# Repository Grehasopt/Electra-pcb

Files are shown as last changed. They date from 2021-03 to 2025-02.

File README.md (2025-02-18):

# Electra
Remote Relays Board

## Electra
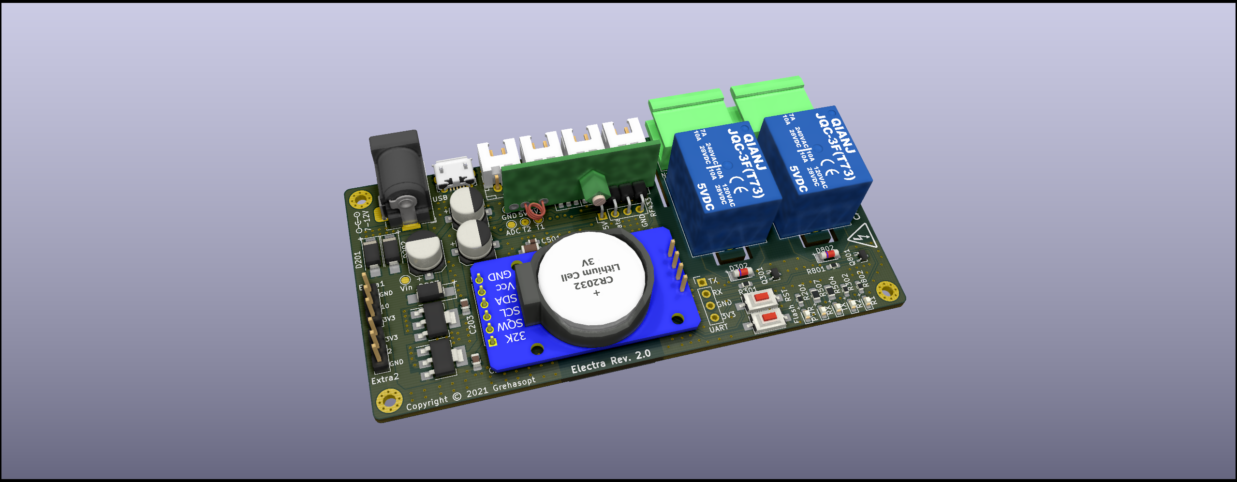
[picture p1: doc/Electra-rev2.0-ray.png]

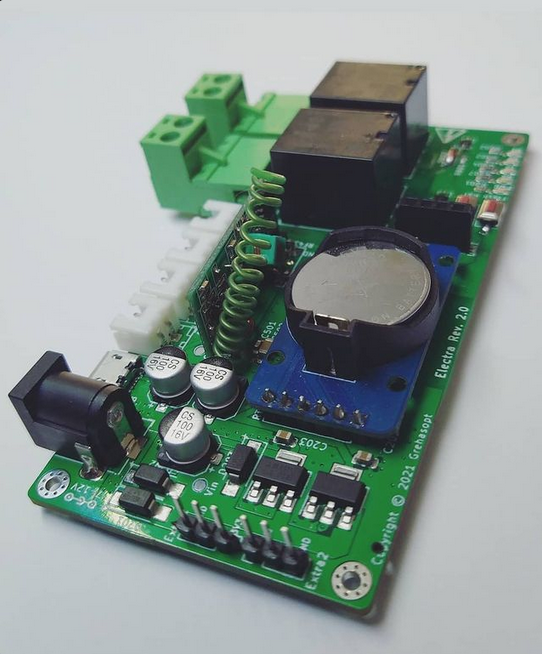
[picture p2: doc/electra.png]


> [!CAUTION]
>
> This project involves the use of 230V AC mains power and contains high-voltage components.
> Working with mains electricity can be extremely dangerous and may result in serious injury,
> death, or property damage if not handled correctly.
>
> This design is provided "as-is" and for educational purposes only.
> Only individuals with the appropriate electrical expertise and experience should attempt to
> reproduce or work with this project. You are solely responsible for ensuring that your work
> with this hardware complies with all applicable safety standards, laws, and regulations.

---

### Schematic

#### Page 1
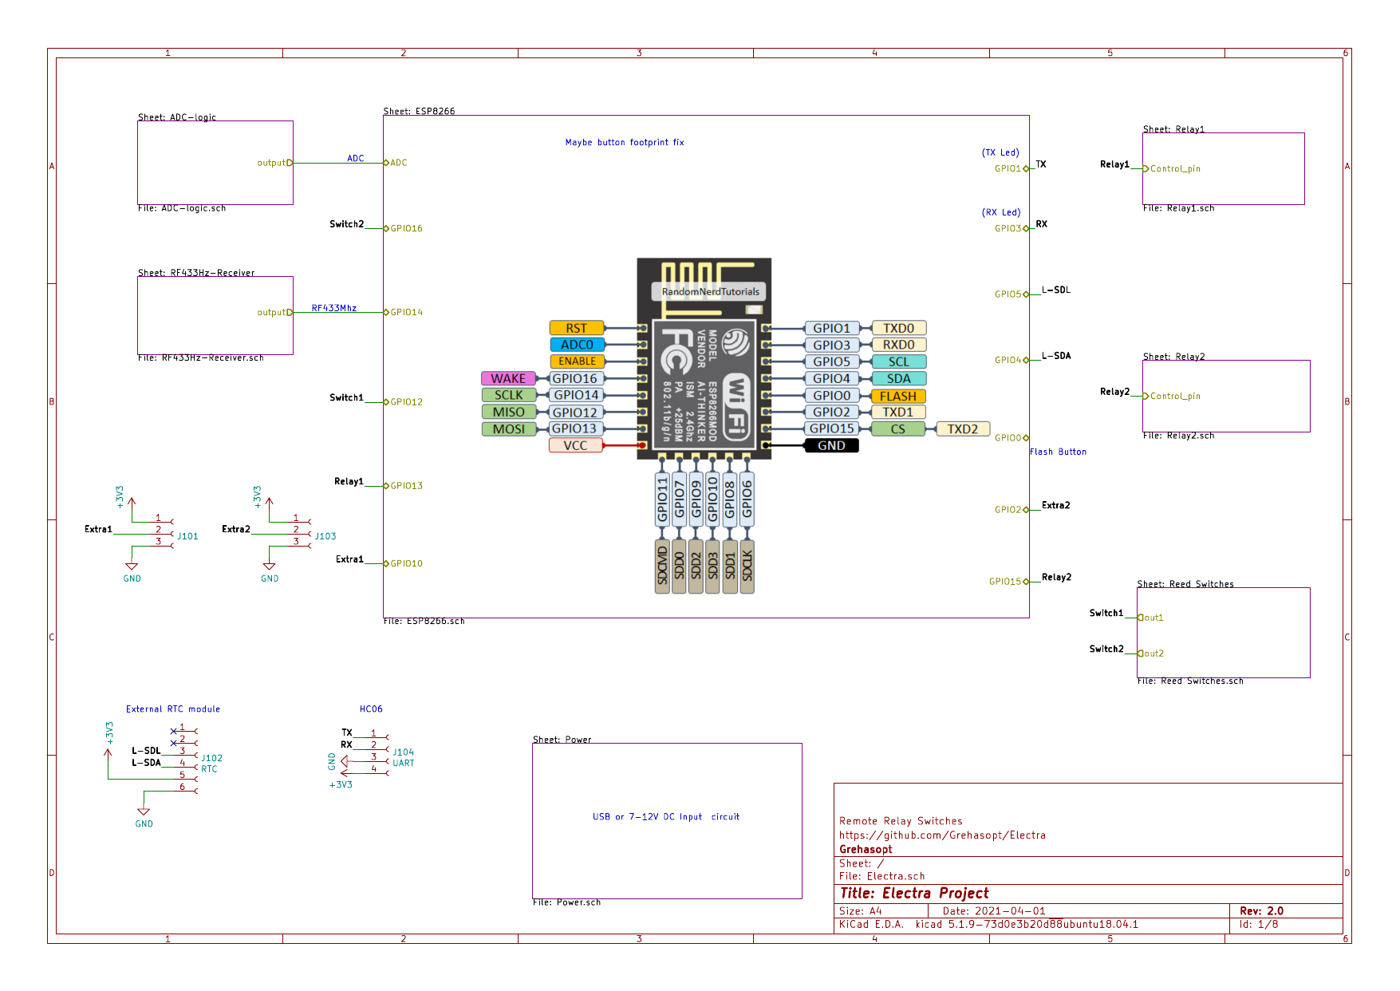
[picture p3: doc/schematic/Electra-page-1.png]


#### Page 2
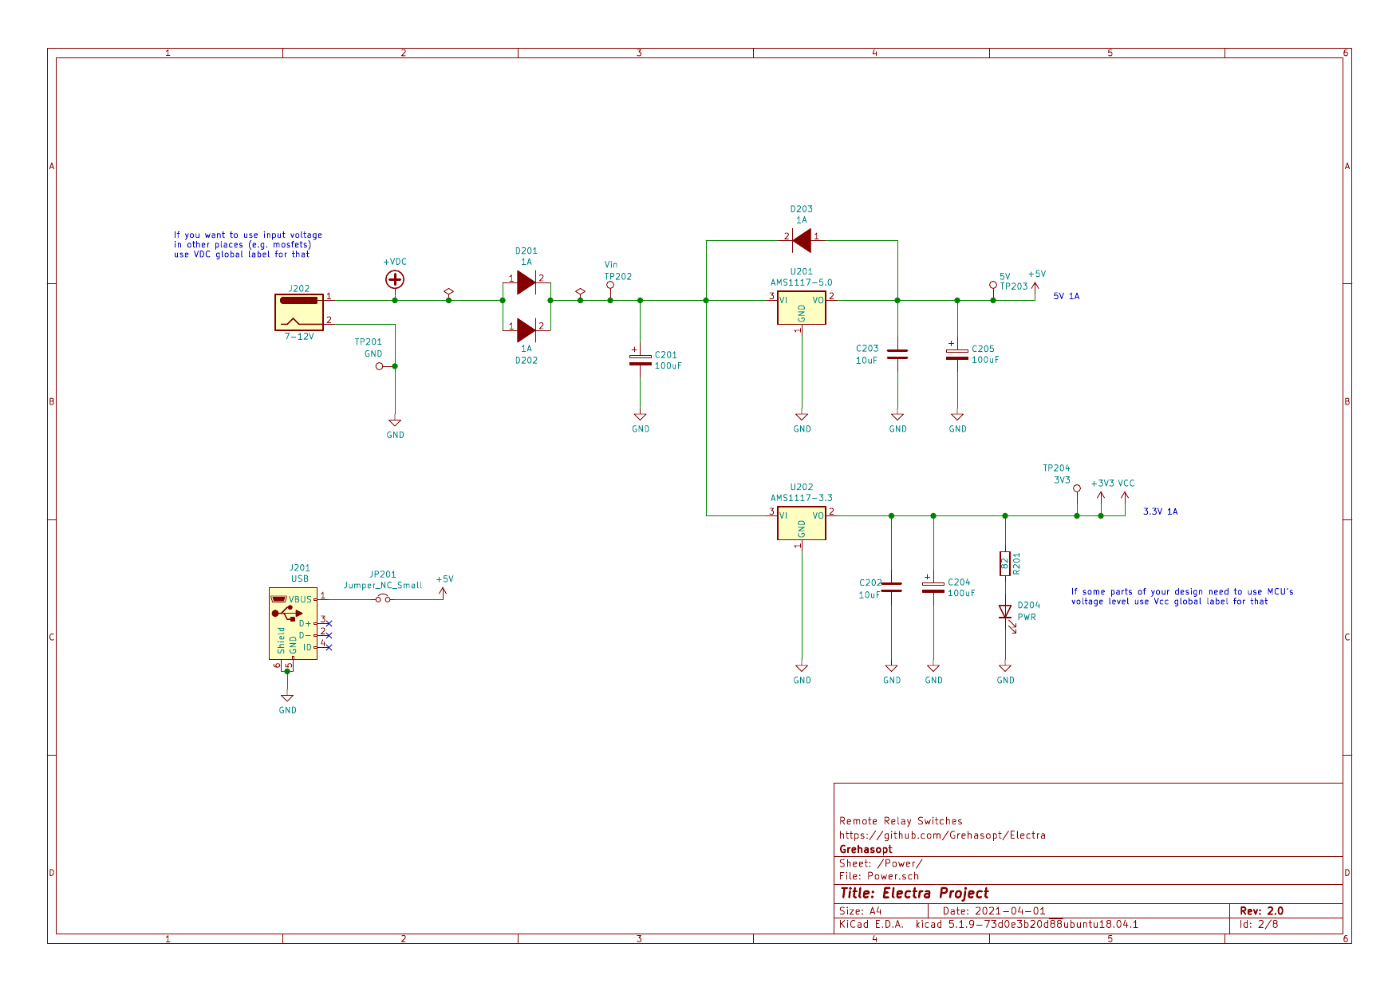
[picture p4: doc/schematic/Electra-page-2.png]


#### Page 3
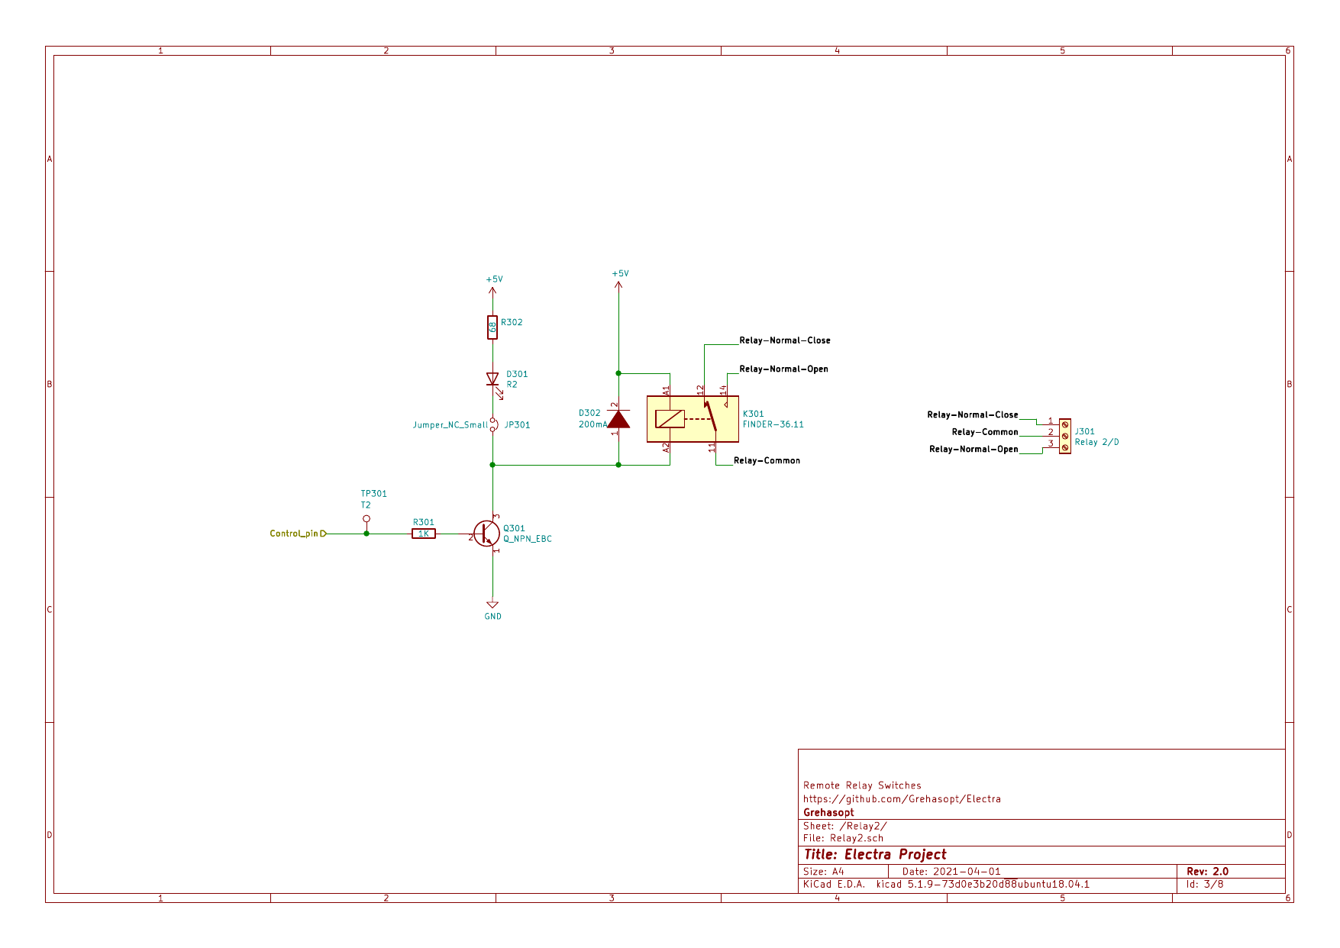
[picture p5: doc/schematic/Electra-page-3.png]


#### Page 4
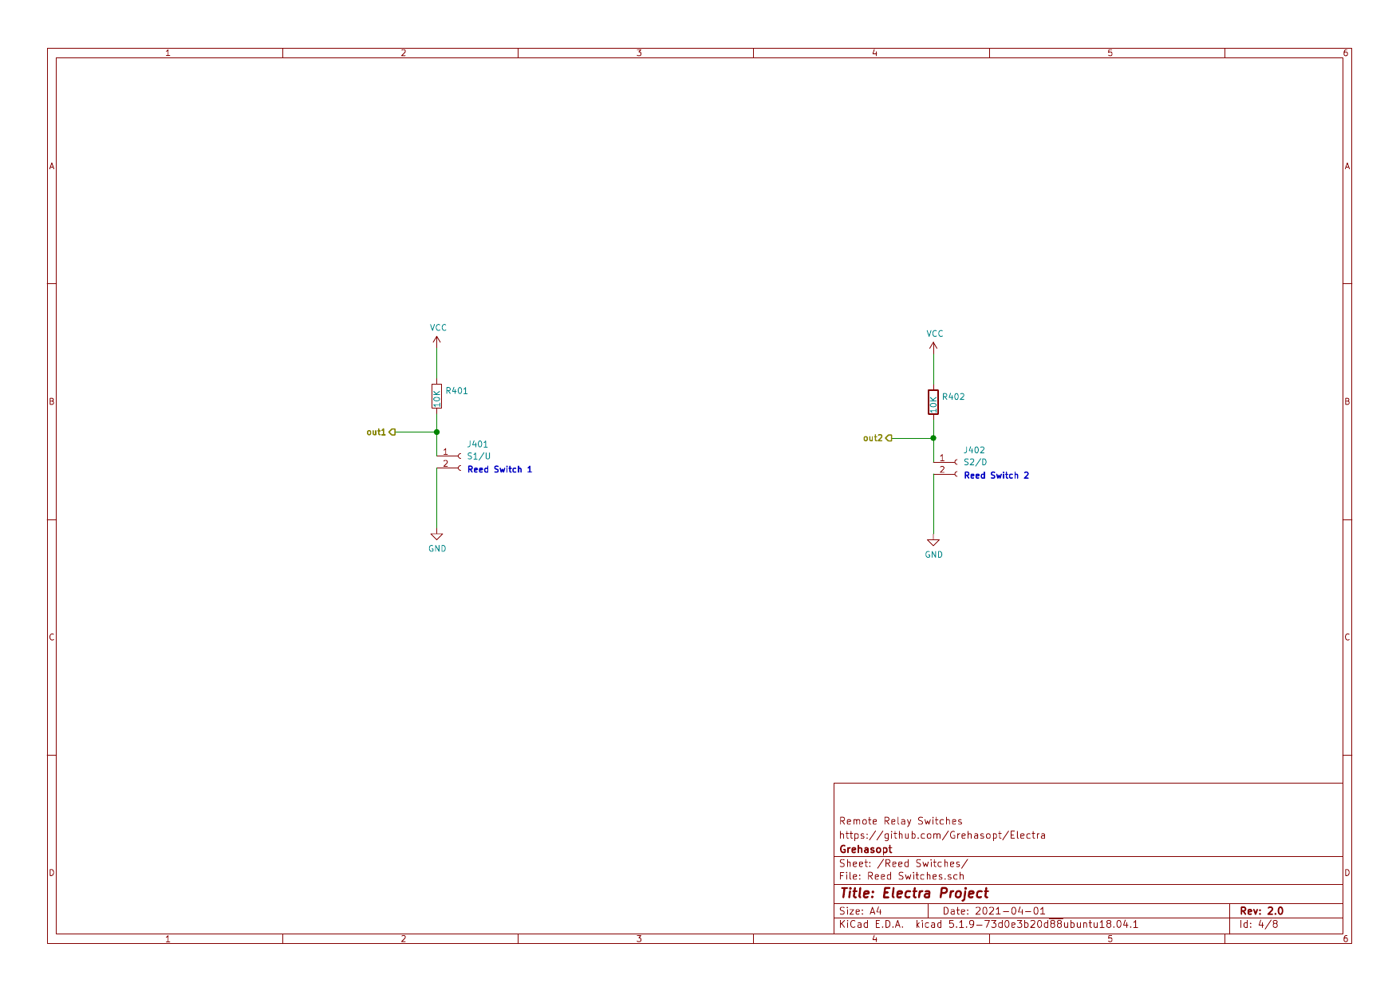
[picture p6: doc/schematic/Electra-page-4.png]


#### Page 5
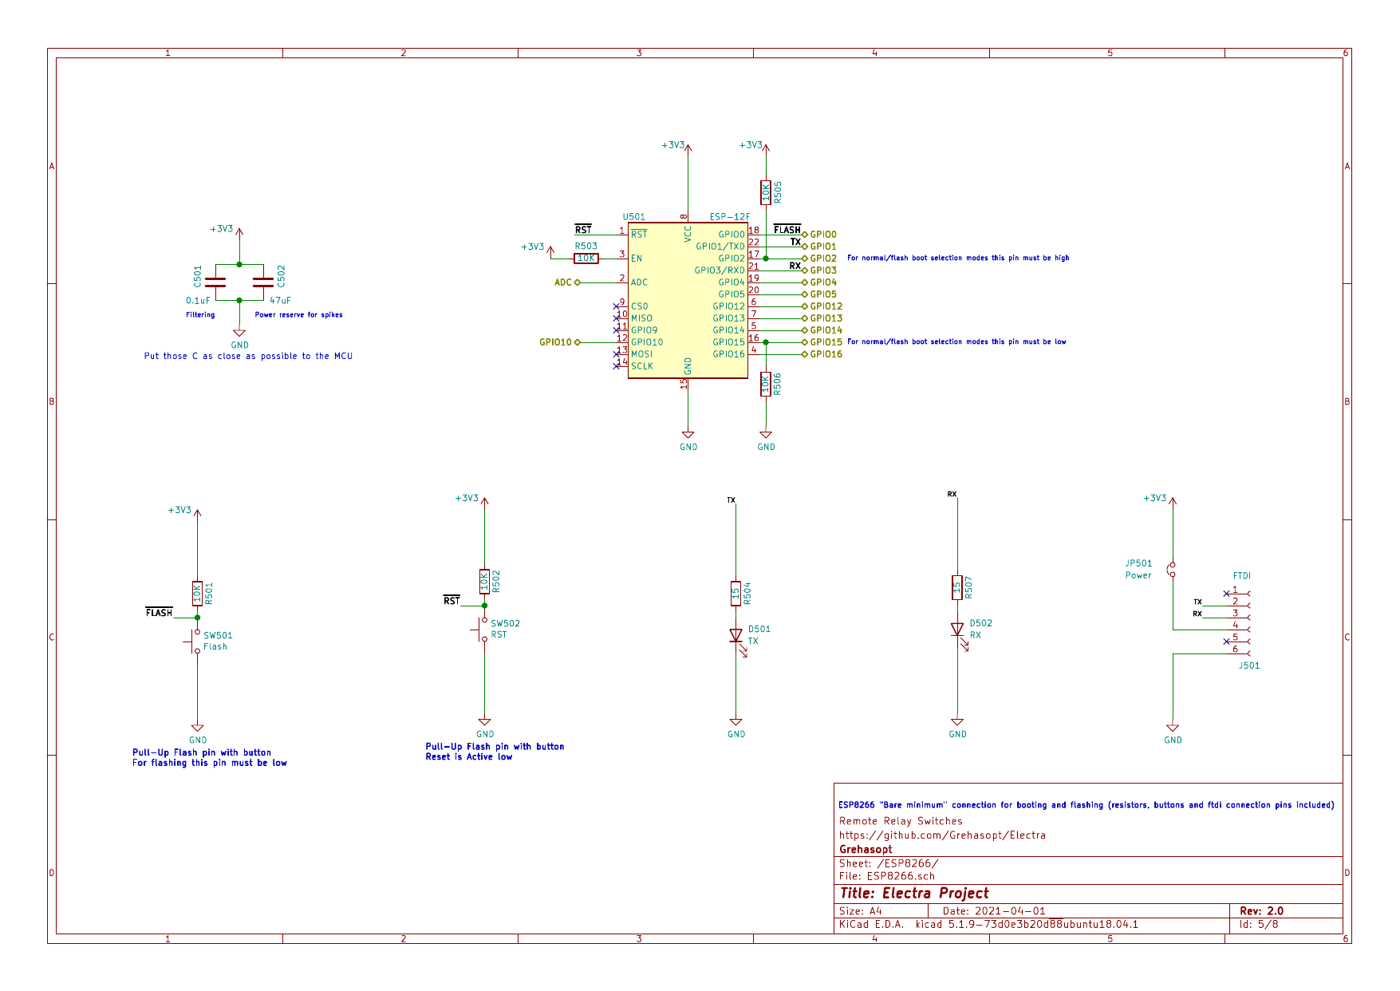
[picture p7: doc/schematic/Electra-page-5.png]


#### Page 6
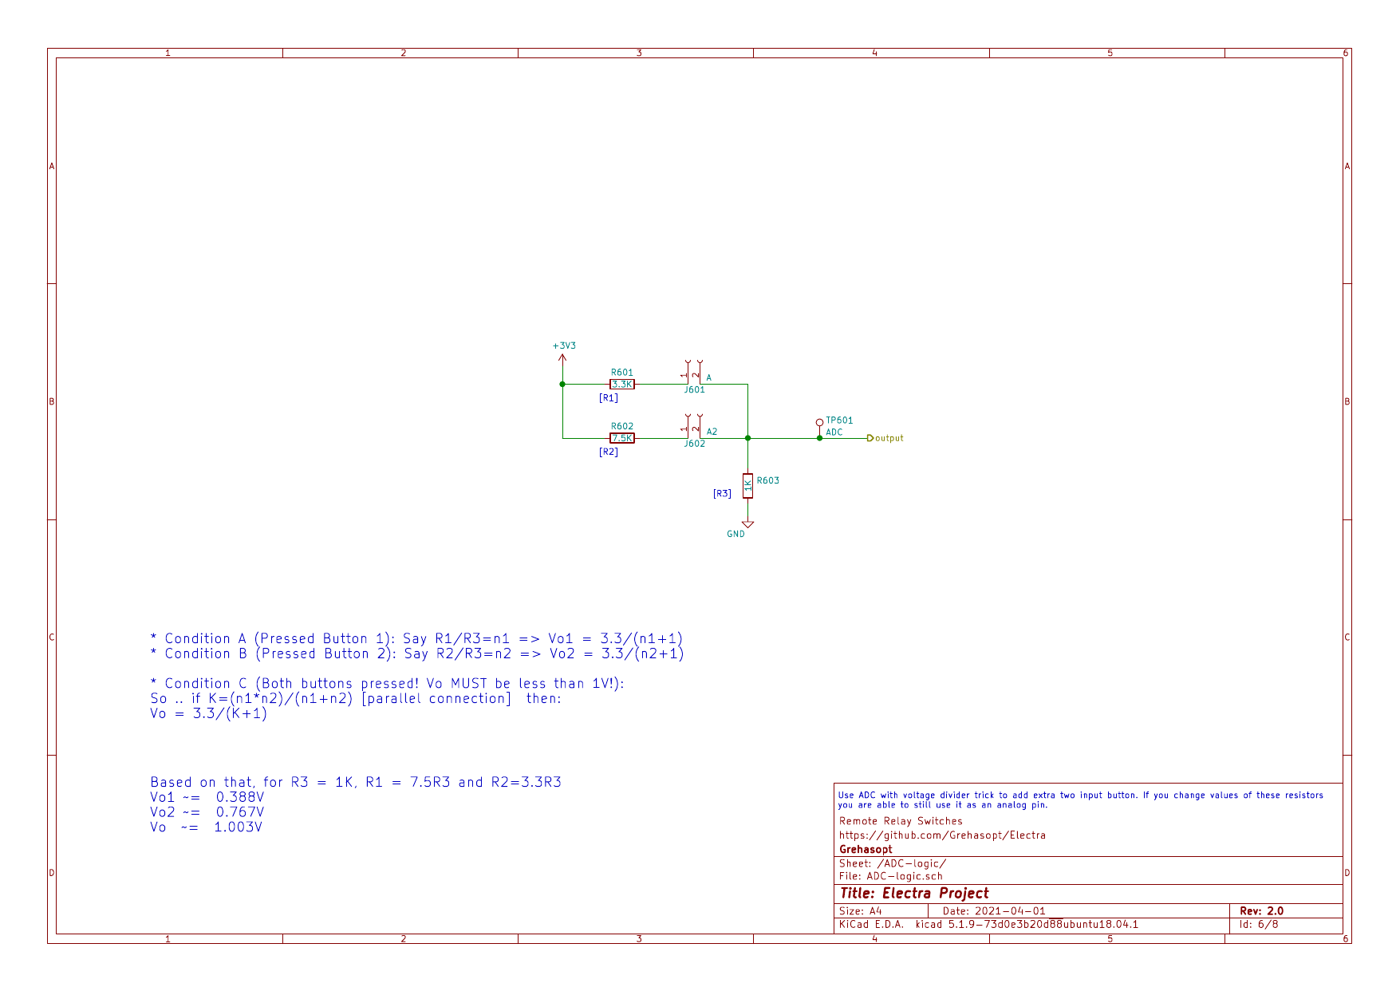
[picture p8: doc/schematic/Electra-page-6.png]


#### Page 7
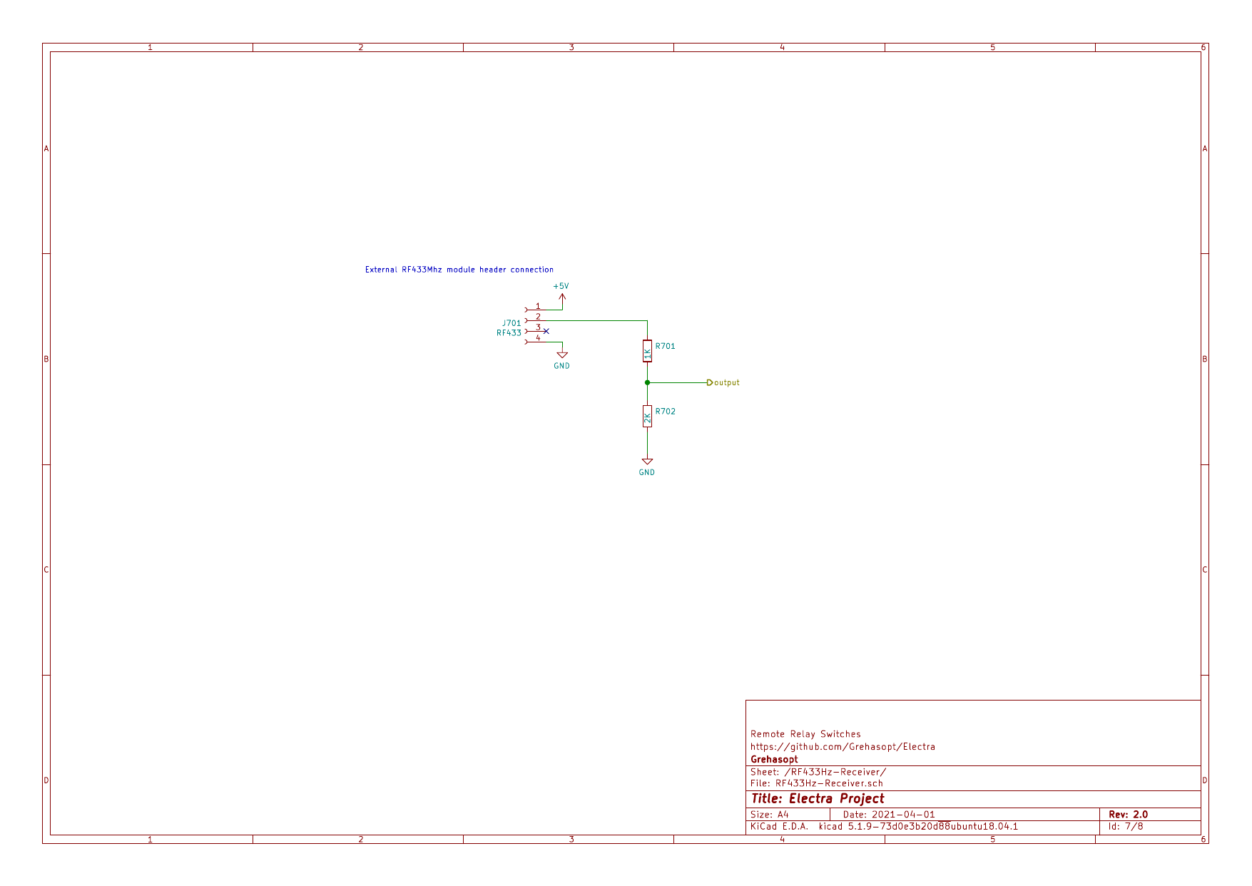
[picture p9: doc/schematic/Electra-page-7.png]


#### Page 8
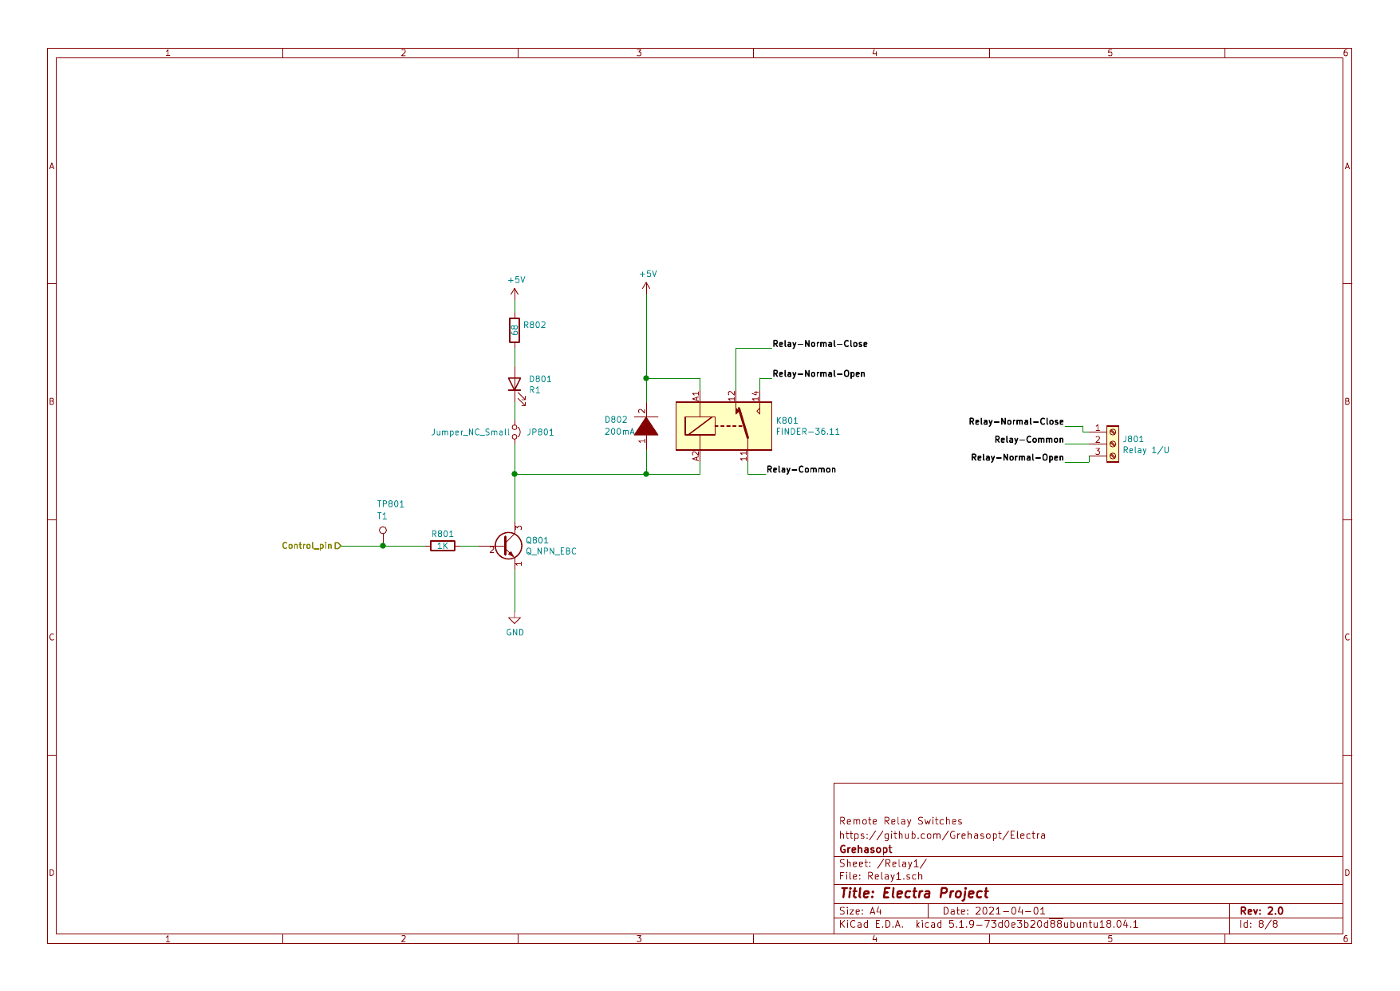
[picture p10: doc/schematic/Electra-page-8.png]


## License
This project is licensed under the CERN-OHL-S-2.0 (applies from the very first commit on Mar 7, 2021) with the added condition that it may not be used for commercial purposes without prior permission from the license holder.

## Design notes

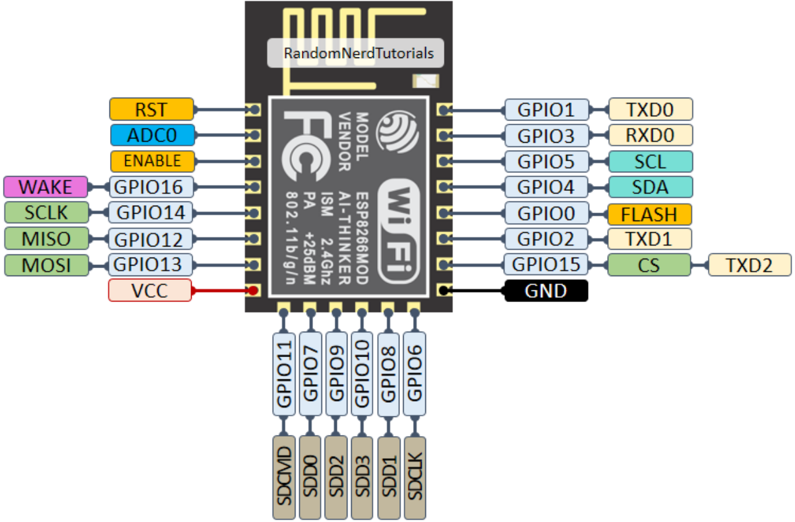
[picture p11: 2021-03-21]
doc/ESP8266-pinout.png

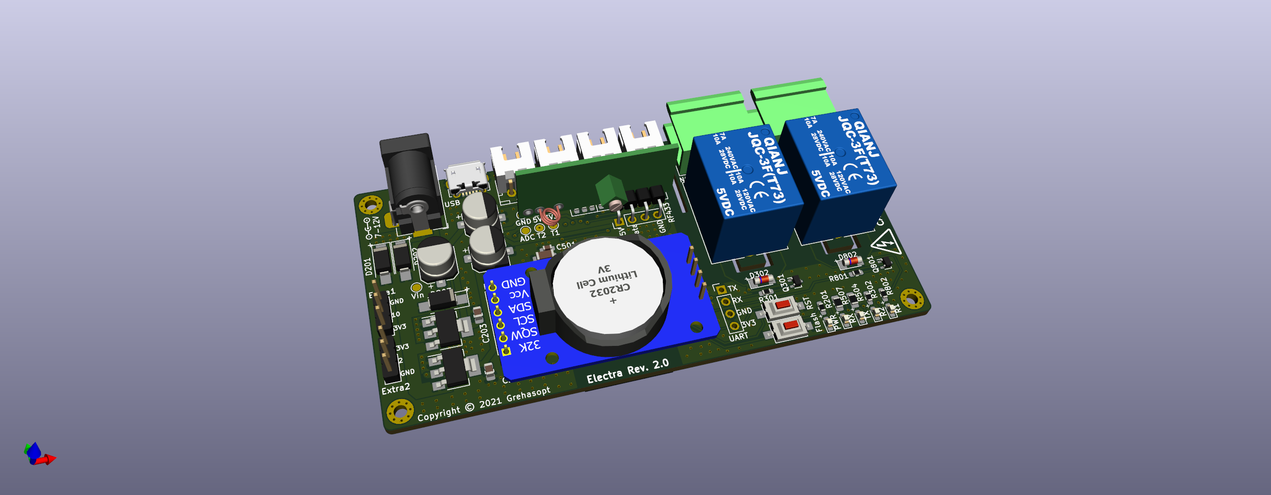
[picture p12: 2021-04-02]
doc/Electra-rev2.0.png

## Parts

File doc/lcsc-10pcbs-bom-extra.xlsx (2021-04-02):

LCSC Part Number | Manufacture Part Number | Manufacturer | Package | Customer # | Description | RoHS | Order Qty. | Min\Mult Order Qty. | Unit Price | Order Price | Product Link
C399562 | HF3FF/005-1ZS | HF(Xiamen Hongfa Electroacoustic) | Through Hole |  | General Purpose Non Latching 5VDC SPDT Through Hole Relays RoHS | yes | 20 | 1 | 0.3517 | 3.87 | lcsc.com/product-detail/Relays_HF-Xiamen-Hongfa-Electroacoustic-HF3FF-005-1ZS_C399562.html
C82891 | ESP-12F(ESP8266MOD) | Ai-Thinker | WIFI Module |  | WIFI Module WIFI Modules RoHS | yes | 10 | 1 | 1.52 | 12.16 | lcsc.com/product-detail/WIFI-Modules_Ai-Thinker-ESP-12F-ESP8266MOD_C82891.html
C71370 | WJ2EDGK-5.08-2P | Ningbo Kangnex Elec | P=5.08mm |  | Plug,Female Socket 2 1 0.200"（5.08mm） 2 P=5.08mm Pluggable System Terminal Block RoHS | yes | 20 | 1 | 0.1028 | 2.06 | lcsc.com/product-detail/Pluggable-System-Terminal-Block_Ningbo-Kangnex-Elec-WJ2EDGK-5-08-2P_C71370.html
C10418 | 920-E52A2021S10100 | Jing Extension of the Electronic Co. | SMD |  | USB - Micro B Female USB 2.0 5 SMD USB Connectors RoHS | yes | 10 | 5 | 0.0663 | 0.66 | lcsc.com/product-detail/USB-Connectors_Jing-Extension-of-the-Electronic-Co-920-E52A2021S10100_C10418.html
C319365 | 1TS002E-2400-2500-CT | HYP (Hongyuan Precision) | SMD,6.1x3.7x2.5mm |  | SPST 50mA @ 12VDC Vertical Rectangle button SMD,6.1x3.7x2.5mm Tactile Switches RoHS | yes | 20 | 20 | 0.0381 | 1.52 | lcsc.com/product-detail/Tactile-Switches_HYP-Hongyuan-Precision-1TS002E-2400-2500-CT_C319365.html
C16214 | DC-005 5.5-2.0MM | BOOMELE(Boom Precision Elec) | Through Hole |  | Through Hole AC/DC Power Plugs & Receptacles RoHS | yes | 20 | 10 | 0.043 | 0.86 | lcsc.com/product-detail/AC-DC-Power-Plugs-Receptacles_BOOMELE-Boom-Precision-Elec-DC-005-5-5-2-0MM_C16214.html
C8425 | WJ2EDGR-5.08-3P | Ningbo Kangnex Elec | P=5.08mm |  | 插针/板端，Covered（2Sided） 3 1 0.200"（5.08mm） 3 P=5.08mm Pluggable System Terminal Block RoHS | yes | 20 | 10 | 0.0508 | 1.02 | lcsc.com/product-detail/Pluggable-System-Terminal-Block_Ningbo-Kangnex-Elec-WJ2EDGR-5-08-3P_C8425.html

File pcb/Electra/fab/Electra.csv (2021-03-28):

Comment | Designator | Footprint | LCSC | Quantity
10uF | C201 | Capacitor_SMD:C_1210_3225Metric_Pad1.33x2.70mm_HandSolder | C92800 | 1
100uF | C203,C208 | Capacitor_SMD:CP_Elec_5x5.4 | C96182 | 2
0.1uF | C202,C204,C601 | Capacitor_SMD:C_0603_1608Metric_Pad1.08x0.95mm_HandSolder | C478888 | 3
22uF | C205,C206 | Capacitor_SMD:C_1210_3225Metric_Pad1.33x2.70mm_HandSolder | C319200 | 2
75pF | C207 | Capacitor_SMD:C_0603_1608Metric_Pad1.08x0.95mm_HandSolder | C1681 | 1
47uF | C602 | Capacitor_SMD:C_0603_1608Metric_Pad1.08x0.95mm_HandSolder | C140782 | 1
DIODE 3A | D201 | Diode_SMD:D_SMA | C18905 | 1
200mA diodes | D302,D402 | Diode_SMD:D_SOD-323 | C89953 | 2
Red led | D301,D401 | LED_SMD:LED_0603_1608Metric_Pad1.05x0.95mm_HandSolder | C84263 | 2
Green led | D202 | LED_SMD:LED_0603_1608Metric_Pad1.05x0.95mm_HandSolder | C205443 | 1
Yellow led | D601,D602 | LED_SMD:LED_0603_1608Metric_Pad1.05x0.95mm_HandSolder | C84268 | 2
8-28V | J201 | Connector_BarrelJack:BarrelJack_Horizontal | C319099 | 1
USB micro b | J202 | Connector_USB:USB_Micro-B_Molex-105017-0001 | C10418 | 1
AC Terminals | J301,J401 | TerminalBlock:TerminalBlock_bornier-3_P5.08mm | C8377 | 2
Relay | K301,K401 | Relay_THT:Relay_SPDT_Finder_36.11 | C9221 | 2
15uH | L201 | Inductor_SMD:L_10.4x10.4_H4.8 | C182182 | 1
200mA NPN BJT | Q301,Q401 | Package_TO_SOT_SMD:SOT-323_SC-70 | C75568 | 2
BSS138 | Q801 | Package_TO_SOT_SMD:SOT-23 | C426569 | 1
511K | R201 | Resistor_SMD:R_0603_1608Metric_Pad0.98x0.95mm_HandSolder | C23194 | 1
105K | R202 | Resistor_SMD:R_0603_1608Metric_Pad0.98x0.95mm_HandSolder | C16840 | 1
80 | R203,R604,R607 | Resistor_SMD:R_0603_1608Metric_Pad0.98x0.95mm_HandSolder | C202954 | 3
49.9 | R204 | Resistor_SMD:R_0603_1608Metric_Pad0.98x0.95mm_HandSolder | C163926 | 1
100K | R205 | Resistor_SMD:R_0603_1608Metric_Pad0.98x0.95mm_HandSolder | C15458 | 1
13.3K | R206 | Resistor_SMD:R_0603_1608Metric_Pad0.98x0.95mm_HandSolder | C25952 | 1
1K | R301,R401,R703 | Resistor_SMD:R_0603_1608Metric_Pad0.98x0.95mm_HandSolder | C115325 | 3
150 | R302,R402 | Resistor_SMD:R_0603_1608Metric_Pad0.98x0.95mm_HandSolder | C103302 | 2
10K | R501,R502,R601,R602,R603,R605,R606,R801,R802 | Resistor_SMD:R_0603_1608Metric_Pad0.98x0.95mm_HandSolder | C98220 | 9
3.57K | R701 | Resistor_SMD:R_0603_1608Metric_Pad0.98x0.95mm_HandSolder | C22998 | 1
7.5K | R702 | Resistor_SMD:R_0603_1608Metric_Pad0.98x0.95mm_HandSolder | C310285 | 1
Buttons | SW601,SW602 | Button_Switch_SMD:SW_SPST_EVQPE1 | C557591 | 2
AMS1117-3.3 | U201 | Package_TO_SOT_SMD:SOT-223-3_TabPin2 | C347222 | 1
TPS54202DDCR | U202 | Package_TO_SOT_SMD:SOT-23-6 | C191884 | 1
ESP-12F | U601 | RF_Module:ESP-12E | C82891 | 1
blue led | DXXX | LED_SMD:LED_0603_1608Metric_Pad1.05x0.95mm_HandSolder | C193191 | 2
blue resistor | RXXX | Resistor_SMD:R_0603_1608Metric_Pad0.98x0.95mm_HandSolder | C319824 | 2
terminal male block | EXX1, EXX2 | - | C71370 | 2

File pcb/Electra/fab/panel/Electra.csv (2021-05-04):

Comment | Designator | Footprint | LCSC
100uF | C201,C204,C205 | Capacitor_SMD:CP_Elec_6.3x5.4 | C97805
10uF | C202,C203 | Capacitor_SMD:C_0805_2012Metric_Pad1.18x1.45mm_HandSolder | C15850
0.1uF | C501 | Capacitor_SMD:C_0603_1608Metric_Pad1.08x0.95mm_HandSolder | C14663
47uF | C502 | Capacitor_SMD:C_1206_3216Metric_Pad1.33x1.80mm_HandSolder | C96123
1A | D201,D202,D203 | Diode_SMD:D_SMA_Handsoldering | C95872
PWR | D204 | LED_SMD:LED_0603_1608Metric_Pad1.05x0.95mm_HandSolder | C72043
R2 | D301 | LED_SMD:LED_0603_1608Metric_Pad1.05x0.95mm_HandSolder | C2286
200mA | D302,D802 | Diode_SMD:D_MiniMELF | C9808
TX | D501 | LED_SMD:LED_0603_1608Metric_Pad1.05x0.95mm_HandSolder | C72041
RX | D502 | LED_SMD:LED_0603_1608Metric_Pad1.05x0.95mm_HandSolder | C72041
R1 | D801 | LED_SMD:LED_0603_1608Metric_Pad1.05x0.95mm_HandSolder | C2286
USB | J201 | Connector_USB:USB_Micro-B_Molex-105017-0001 | C10418
7-12V | J202 | Connector_BarrelJack:BarrelJack_Horizontal | C16214
Relay 2/D | J301 | TerminalBlock:TerminalBlock_bornier-3_P5.08mm | C8425
Relay 1/U | J801 | TerminalBlock:TerminalBlock_bornier-3_P5.08mm | C8425
FINDER-36.11 | K301,K801 | Relay_THT:Relay_SPDT_Finder_36.11 | C399562
Q_NPN_EBC | Q301,Q801 | Package_TO_SOT_SMD:SOT-323_SC-70 | C75568
82 | R201 | Resistor_SMD:R_0603_1608Metric_Pad0.98x0.95mm_HandSolder | C23255
1K | R301,R603,R701,R801 | Resistor_SMD:R_0603_1608Metric_Pad0.98x0.95mm_HandSolder | C21190
68 | R302,R802 | Resistor_SMD:R_0603_1608Metric_Pad0.98x0.95mm_HandSolder | C27592
10K | R401,R402,R501,R502,R503,R505,R506 | Resistor_SMD:R_0603_1608Metric_Pad0.98x0.95mm_HandSolder | C25804
15 | R504,R507 | Resistor_SMD:R_0805_2012Metric_Pad1.20x1.40mm_HandSolder | C17480
3.3K | R601 | Resistor_SMD:R_0603_1608Metric_Pad0.98x0.95mm_HandSolder | C22978
7.5K | R602 | Resistor_SMD:R_0603_1608Metric_Pad0.98x0.95mm_HandSolder | C23234
2K | R702 | Resistor_SMD:R_0603_1608Metric_Pad0.98x0.95mm_HandSolder | C22975
Flash | SW501 | Button_Switch_SMD:SW_SPST_CK_RS282G05A3 | C329185
RST | SW502 | Button_Switch_SMD:SW_SPST_CK_RS282G05A3 | C329185
AMS1117-5.0 | U201 | Package_TO_SOT_SMD:SOT-223-3_TabPin2 | C6187
AMS1117-3.3 | U202 | Package_TO_SOT_SMD:SOT-223-3_TabPin2 | C6186
ESP-12F | U501 | RF_Module:ESP-12E | C82891

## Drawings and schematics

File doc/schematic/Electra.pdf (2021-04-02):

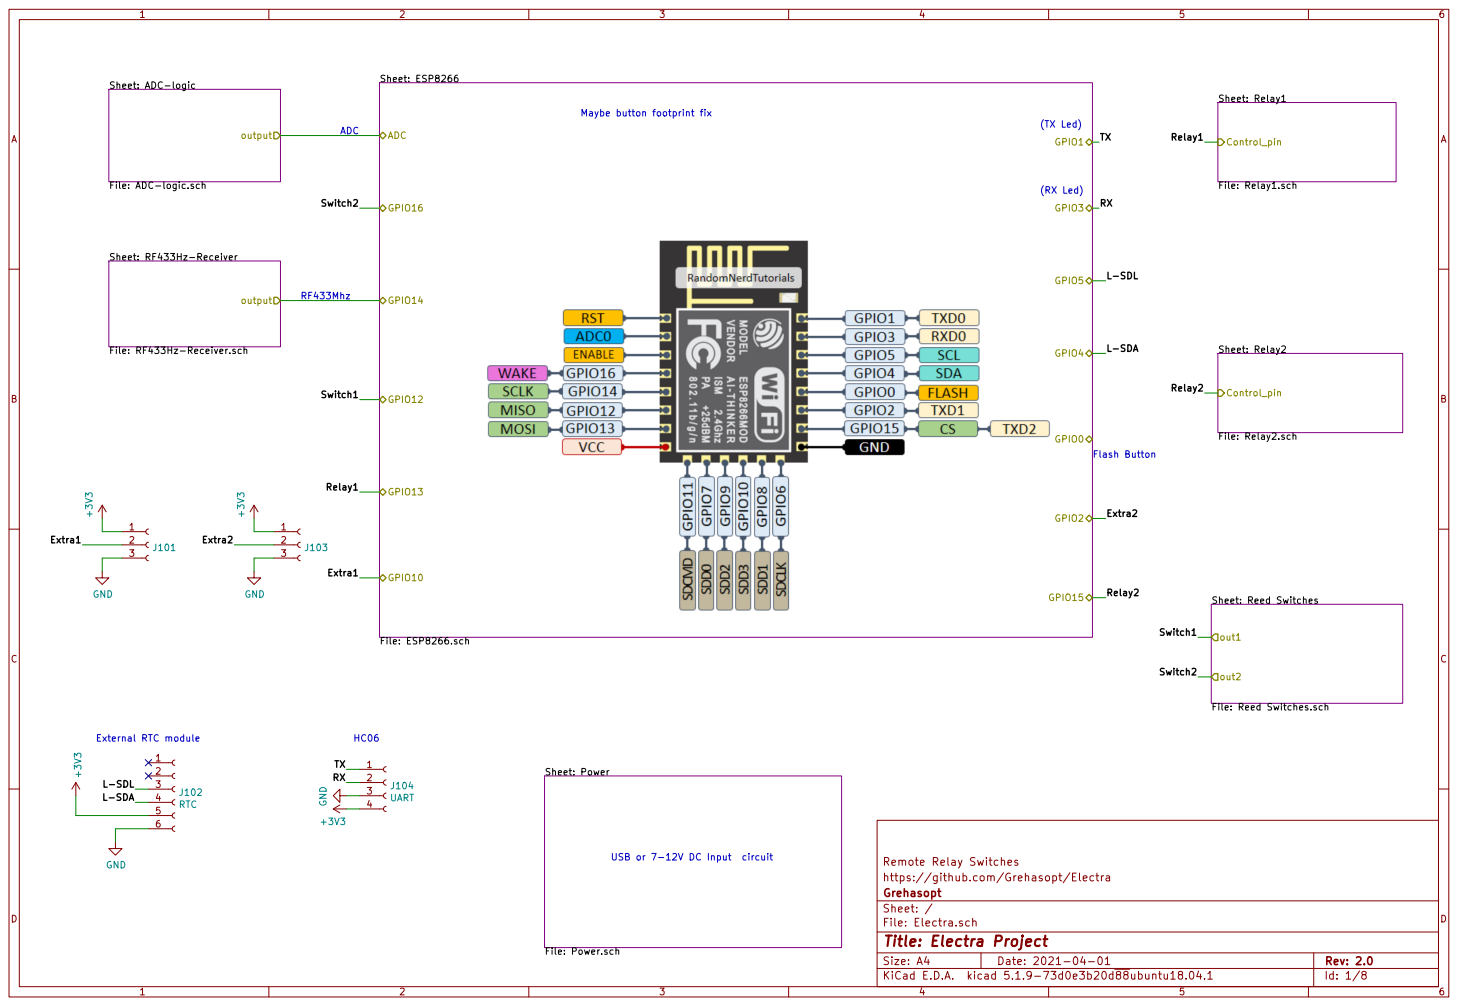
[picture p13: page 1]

output Sheet: ADC-logic

Control_pin Sheet: RF433Hz-Receiver File: RF433Hz-Receiver.sch

File: ADC-logic.sch

L-SDA
Control_pin Sheet: Reed Switches File: Reed Switches.sch

Remote Relay Switches
https://github.com/Grehasopt/Electra
Id: 1/8 Title: Electra Project File: Electra.sch Sheet: / Grehasopt

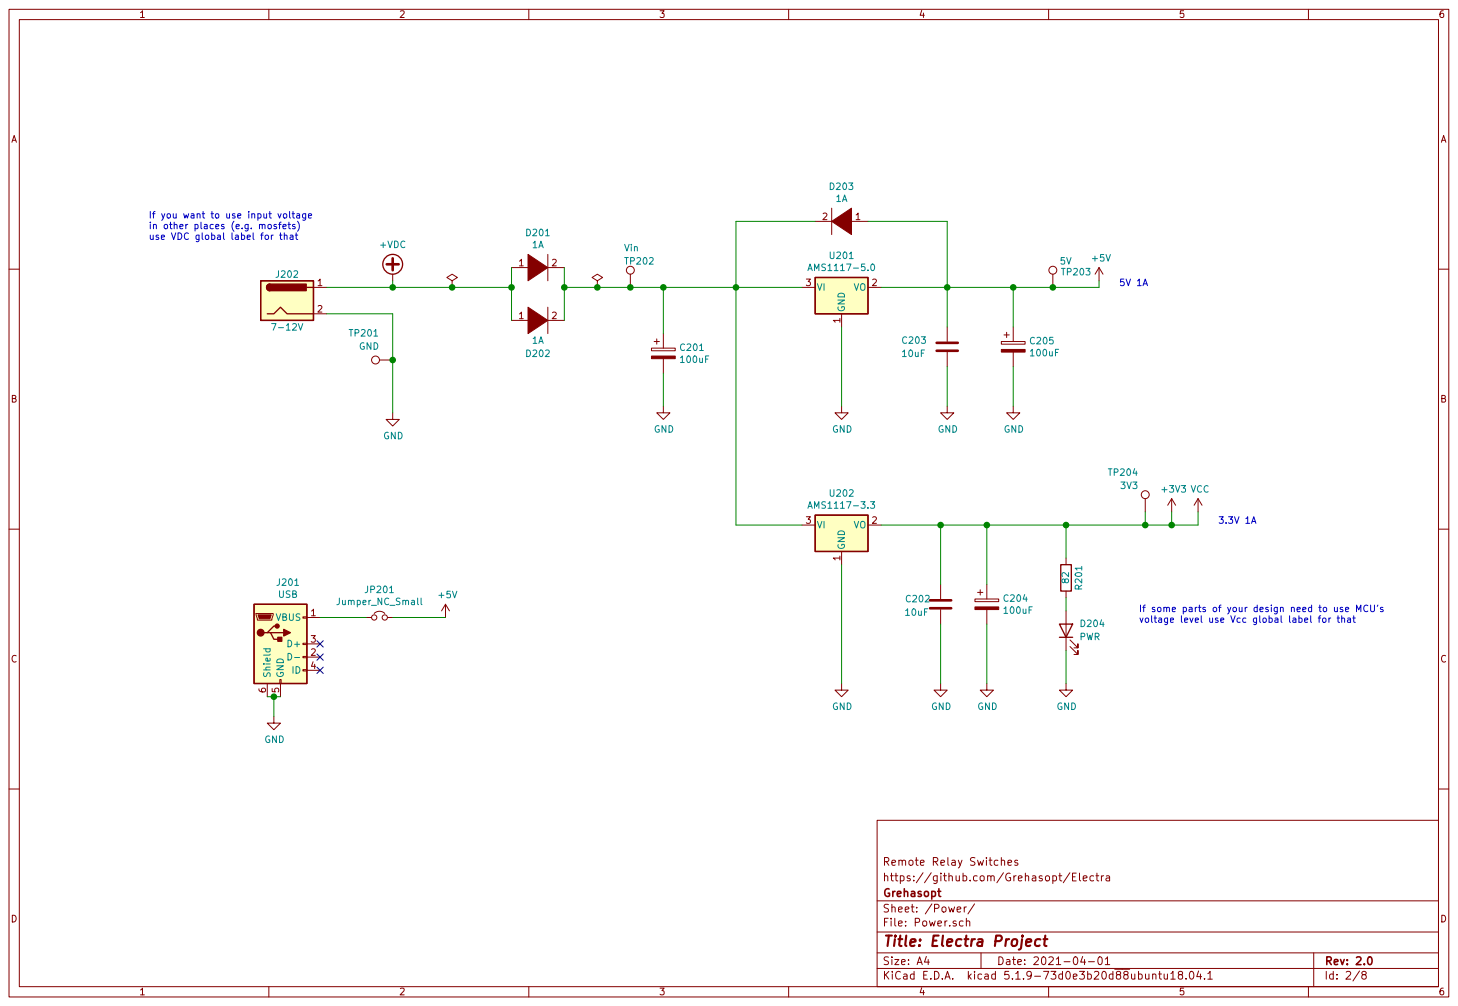
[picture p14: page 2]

If you want to use input voltage
in other places (e.g. mosfets)

voltage level use Vcc global label for that 5V 1A

If some parts of your design need to use MCU's

https://github.com/Grehasopt/Electra
Id: 2/8 Title: Electra Project File: Power.sch Sheet: /Power/ Grehasopt

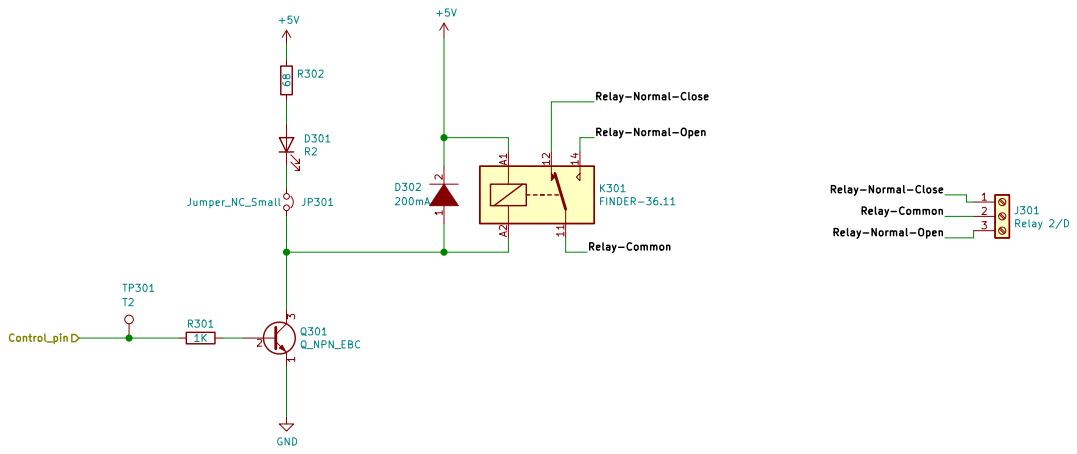
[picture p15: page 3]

https://github.com/Grehasopt/Electra
Grehasopt
Sheet: /Relay2/
File: Relay2.sch
Id: 3/8 Title: Electra Project

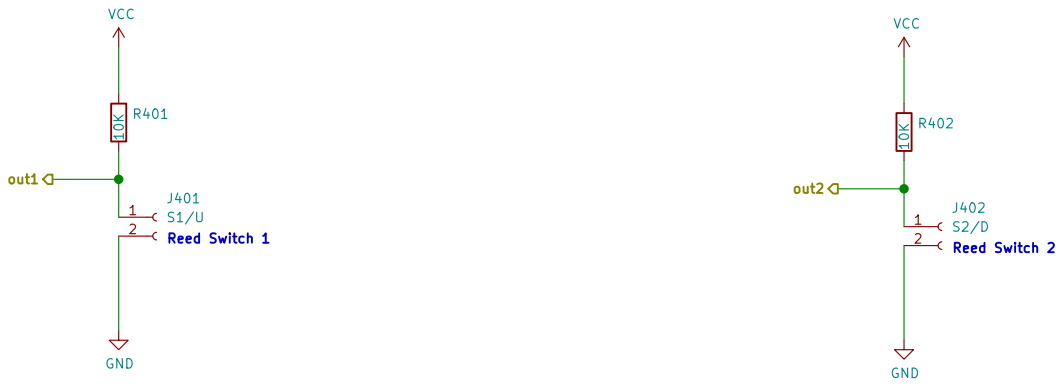
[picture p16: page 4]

Remote Relay Switches
https://github.com/Grehasopt/Electra
Id: 4/8 Title: Electra Project File: Reed Switches.sch Sheet: /Reed Switches/ Grehasopt

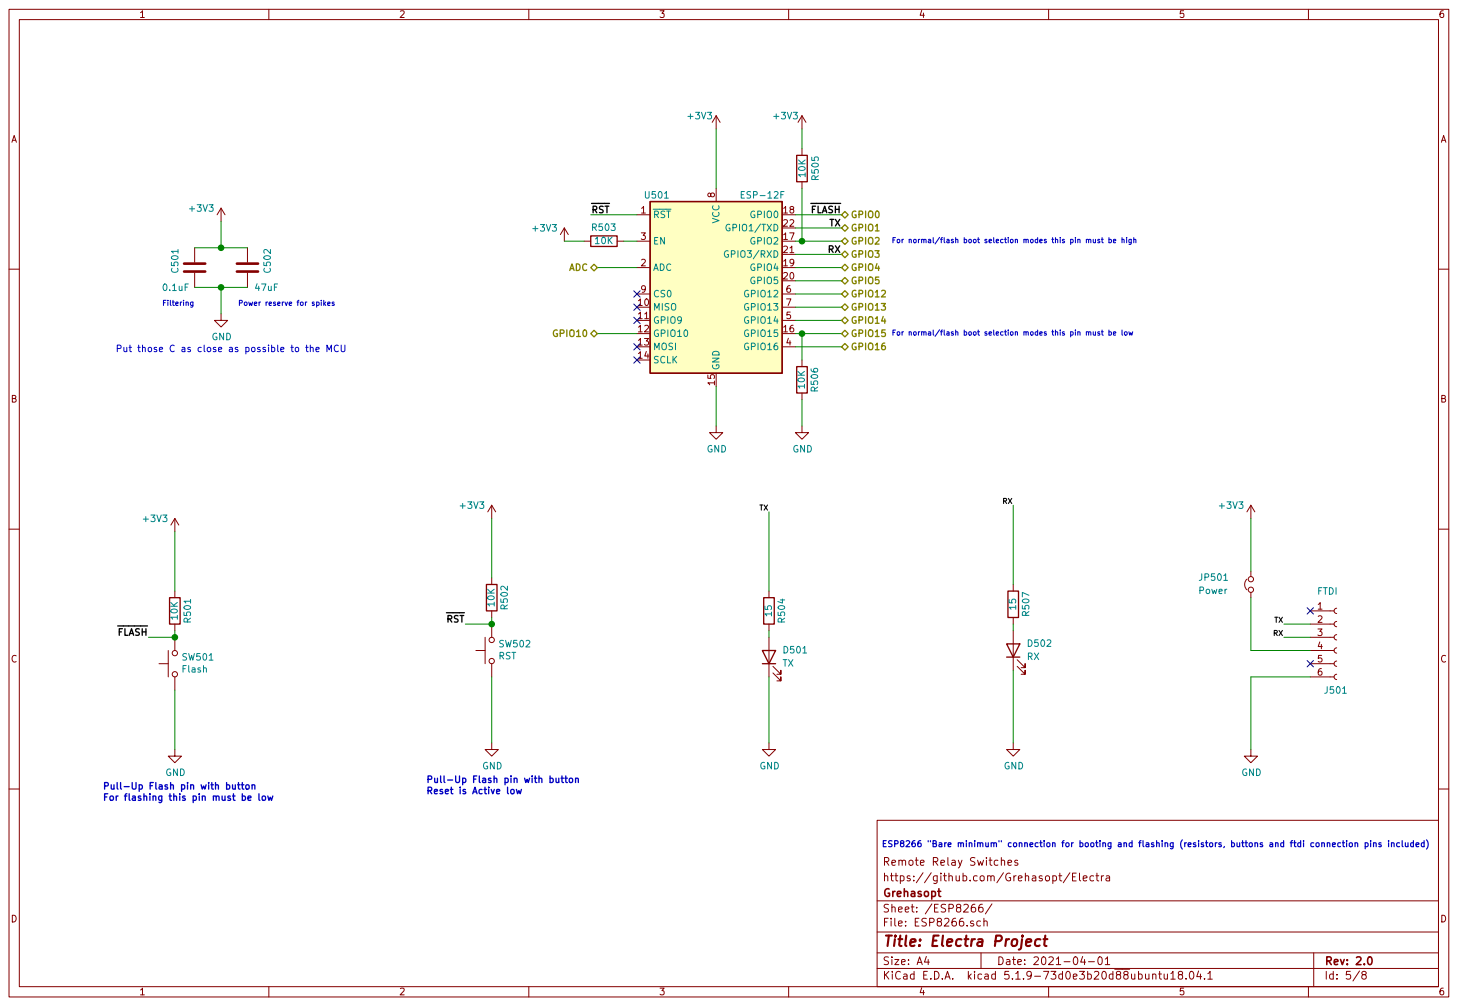
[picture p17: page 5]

For normal/flash boot selection modes this pin must be high

For normal/flash boot selection modes this pin must be low

ESP8266 "Bare minimum" connection for booting and flashing (resistors, buttons and ftdi connection pins included) Pull-Up Flash pin with button
For flashing this pin must be low

Pull-Up Flash pin with button Reset is Active low

Remote Relay Switches
https://github.com/Grehasopt/Electra
Id: 5/8 Title: Electra Project File: ESP8266.sch Sheet: /ESP8266/ Grehasopt

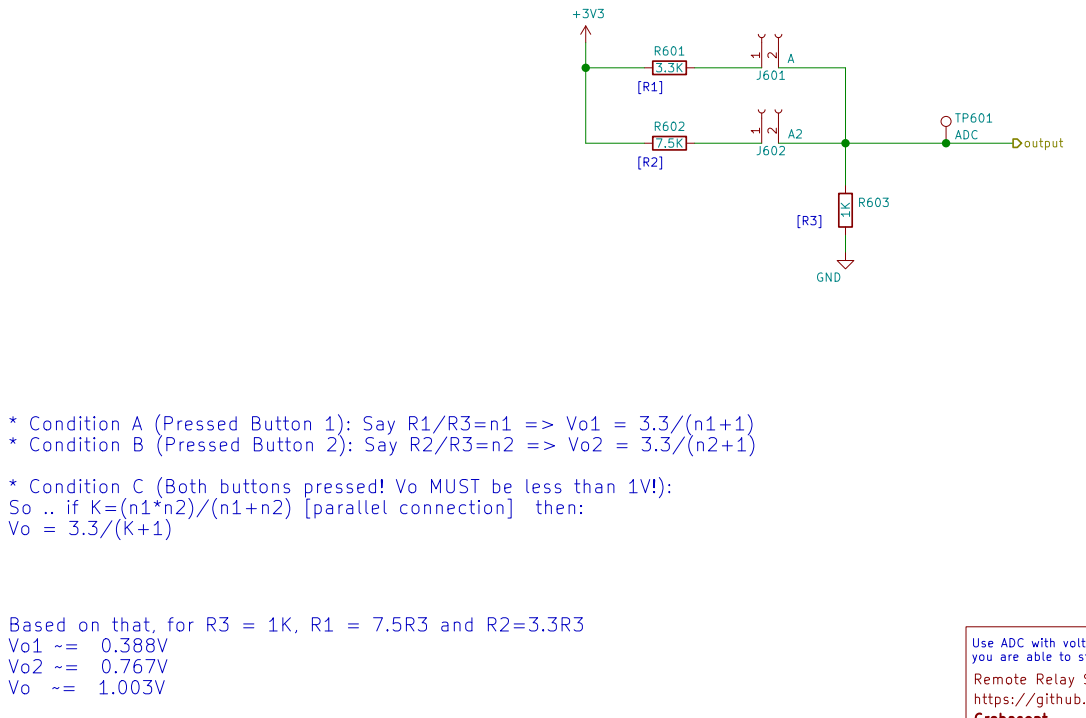
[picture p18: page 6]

output Based on that, for R3 = 1K, R1 = 7.5R3 and R2=3.3R3

* Condition A (Pressed Button 1): Say R1/R3=n1 => Vo1 = 3.3/(n1+1)
* Condition B (Pressed Button 2): Say R2/R3=n2 => Vo2 = 3.3/(n2+1)
* Condition C (Both buttons pressed! Vo MUST be less than 1V!):
So .. if K=(n1*n2)/(n1+n2) [parallel connection] then:

Use ADC with voltage divider trick to add extra two input button. If you change values of these resistors
you are able to still use it as an analog pin.

https://github.com/Grehasopt/Electra
Grehasopt
Sheet: /ADC-logic/
File: ADC-logic.sch
Id: 6/8 Title: Electra Project

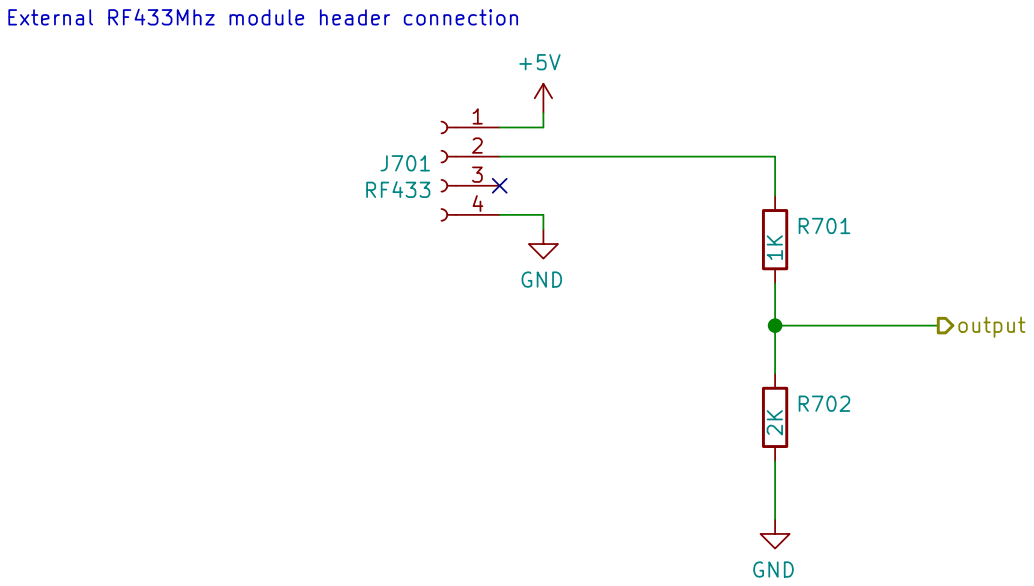
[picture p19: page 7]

output External RF433Mhz module header connection

Remote Relay Switches
https://github.com/Grehasopt/Electra
Id: 7/8 Title: Electra Project File: RF433Hz-Receiver.sch Sheet: /RF433Hz-Receiver/ Grehasopt

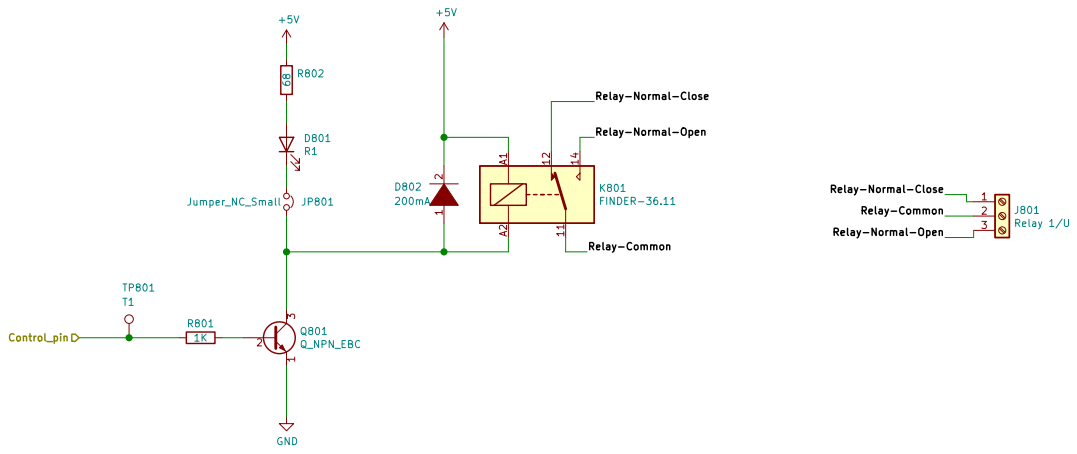
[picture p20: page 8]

https://github.com/Grehasopt/Electra
Grehasopt
Sheet: /Relay1/
File: Relay1.sch
Id: 8/8 Title: Electra Project

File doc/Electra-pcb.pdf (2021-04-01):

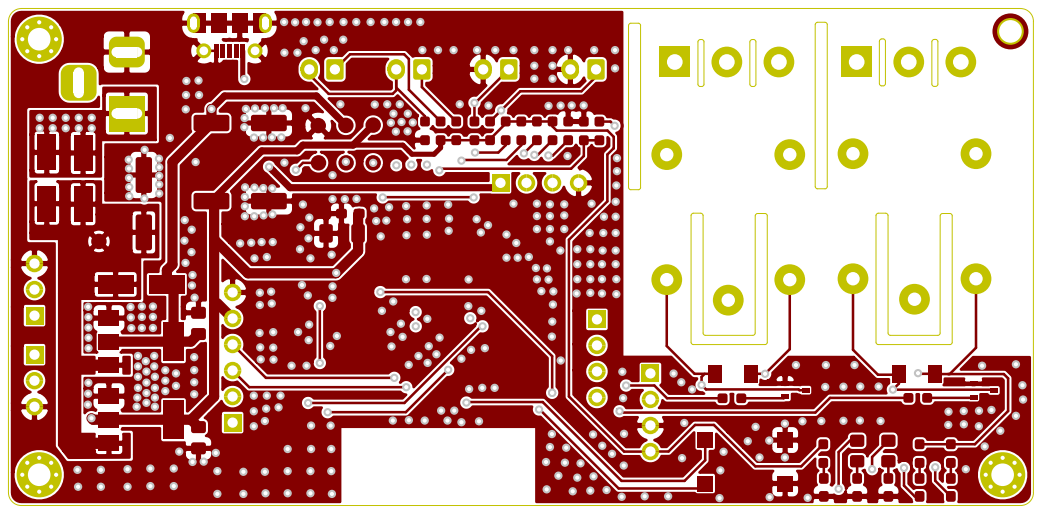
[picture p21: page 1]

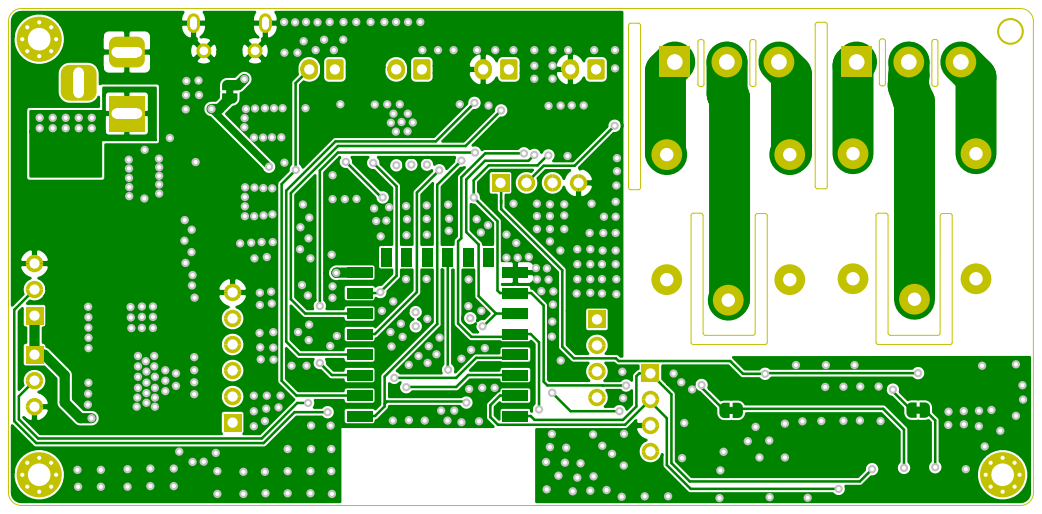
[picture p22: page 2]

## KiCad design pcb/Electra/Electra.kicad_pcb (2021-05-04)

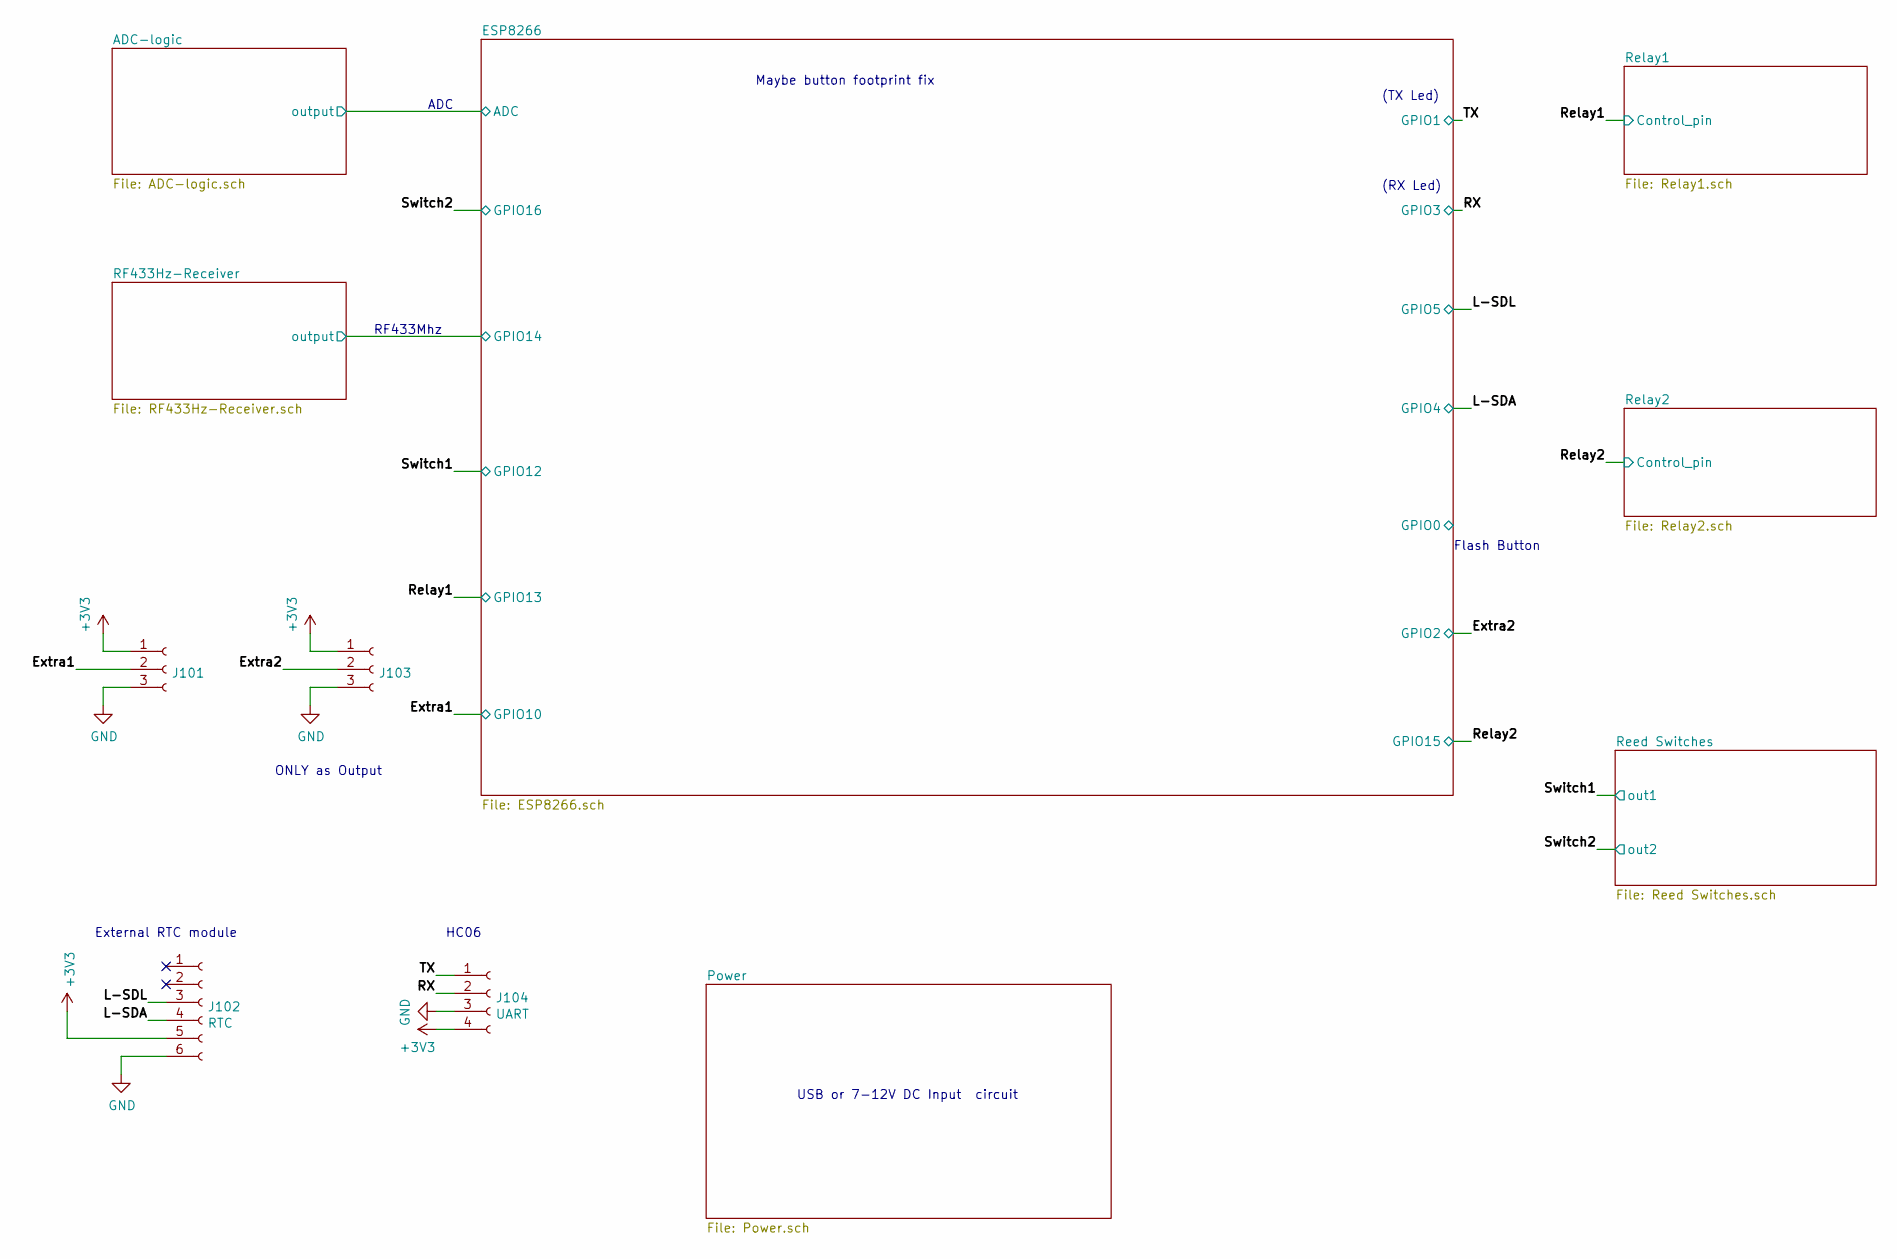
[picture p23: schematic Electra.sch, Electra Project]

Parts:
J101: Extra1; PinHeader_1x03_P2.54mm_Vertical
J102: RTC; PinHeader_1x06_P2.54mm_Vertical
J103: Extra2; PinHeader_1x03_P2.54mm_Vertical
J104: UART; PinHeader_1x04_P2.54mm_Vertical

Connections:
+3V3: J101.1, J102.5, J103.1, J104.4; also elsewhere on the board
/Extra1: J101.2; also elsewhere on the board
/Extra2: J103.2; also elsewhere on the board
/L-SDA: J102.4; also elsewhere on the board
/L-SDL: J102.3; also elsewhere on the board
/RX: J104.2; also elsewhere on the board
/TX: J104.1; also elsewhere on the board
GND: J101.3, J102.6, J103.3, J104.3; also elsewhere on the board

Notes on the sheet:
External RTC module
(TX Led)
(RX Led)
Flash Button
USB or 7-12V DC Input circuit
HC06
RF433Mhz
ADC
Maybe button footprint fix
ONLY as Output

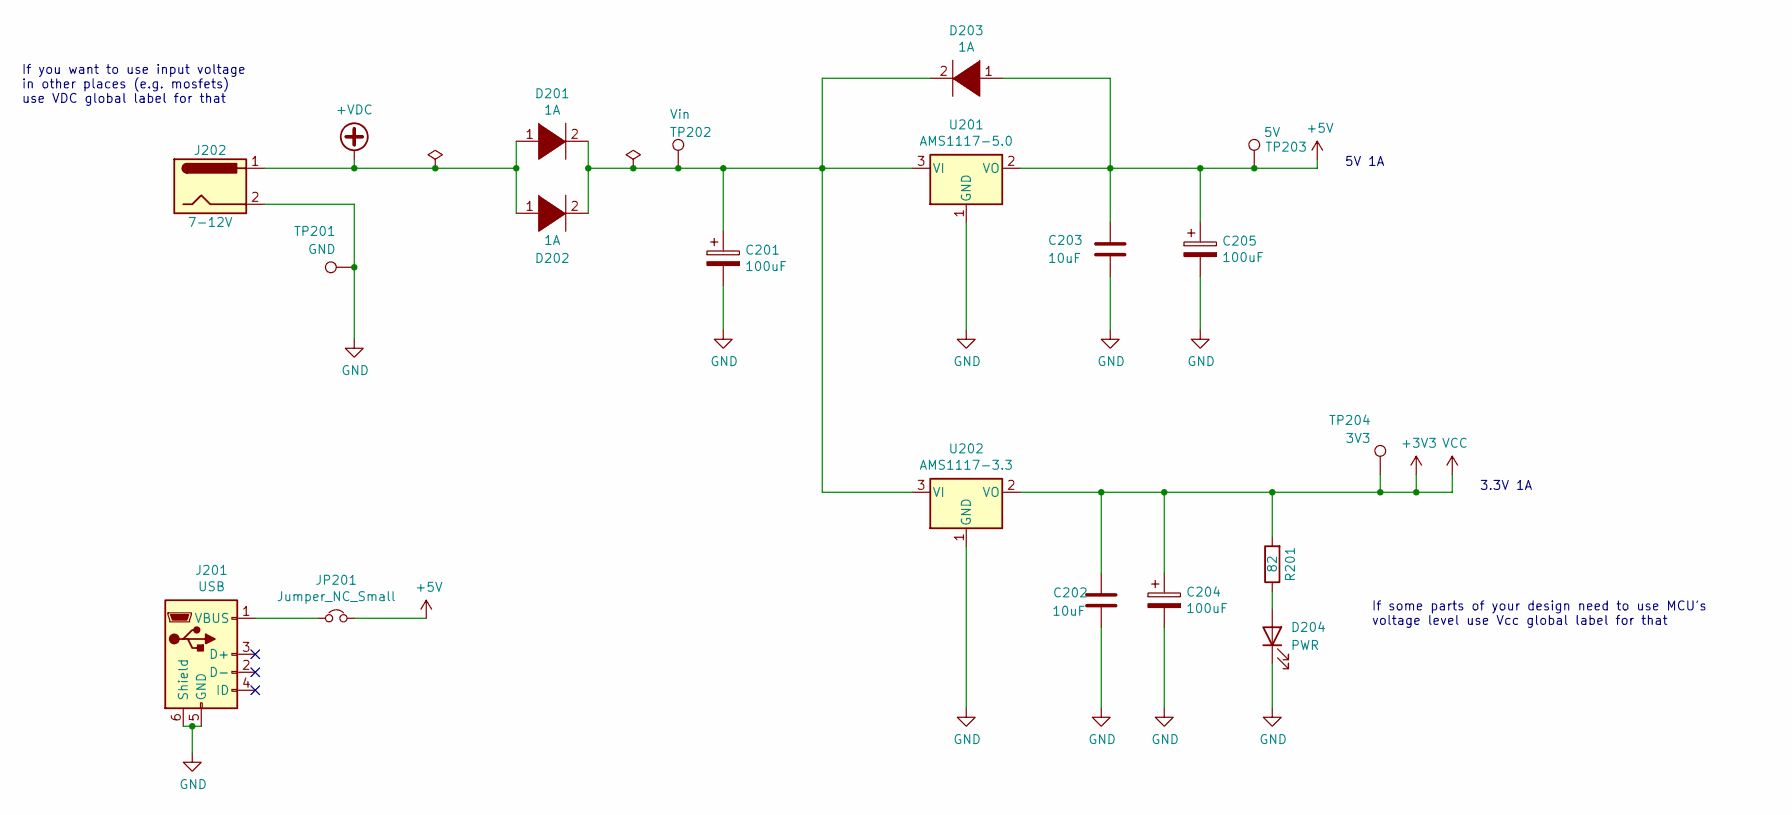
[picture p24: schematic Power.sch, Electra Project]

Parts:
C201, C204, C205: 100uF; CP_Elec_6.3x5.4; LCSC C97805
C202, C203: 10uF; C_0805_2012Metric_Pad1.18x1.45mm_HandSolder; LCSC C15850
D201, D202, D203: 1A; D_SMA_Handsoldering; LCSC C95872
D204: PWR; LED_0603_1608Metric_Pad1.05x0.95mm_HandSolder; LCSC C72043
J201: USB; USB_Micro-B_Molex-105017-0001; LCSC C10418
J202: 7-12V; BarrelJack_Horizontal; LCSC C16214
JP201: Jumper_NC_Small; SolderJumper-2_P1.3mm_Bridged_RoundedPad1.0x1.5mm
R201: 82; R_0603_1608Metric_Pad0.98x0.95mm_HandSolder; LCSC C23255
TP201: GND; TestPoint_Pad_D1.5mm
TP202: Vin; TestPoint_Pad_D1.5mm
TP203: 5V; TestPoint_Pad_D1.5mm
TP204: 3V3; TestPoint_Pad_D1.5mm
U201: AMS1117-5.0; SOT-223-3_TabPin2; LCSC C6187
U202: AMS1117-3.3; SOT-223-3_TabPin2; LCSC C6186

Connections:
+3V3: C202.1, C204.1, R201.2, TP204.1, U202.2 (VO); also elsewhere on the board
+5V: C203.1, C205.1, D203.1 (K), JP201.2, TP203.1, U201.2 (VO); also elsewhere on the board
+VDC: D201.1 (K), D202.1 (K), J202.1
GND: C201.2, C202.2, C203.2, C204.2, C205.2, D204.1 (K), J201.5 (GND), J201.6 (Shield), J202.2, TP201.1, U201.1 (GND), U202.1 (GND); also elsewhere on the board
unnamed: C201.1, D201.2 (A), D202.2 (A), D203.2 (A), TP202.1, U201.3 (VI), U202.3 (VI)
unnamed: D204.2 (A), R201.1
unnamed: J201.1 (VBUS), JP201.1

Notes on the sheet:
If you want to use input voltage in other places (e.g. mosfets) use VDC global label for that
If some parts of your design need to use MCU's voltage level use Vcc global label for that
5V 1A
3.3V 1A

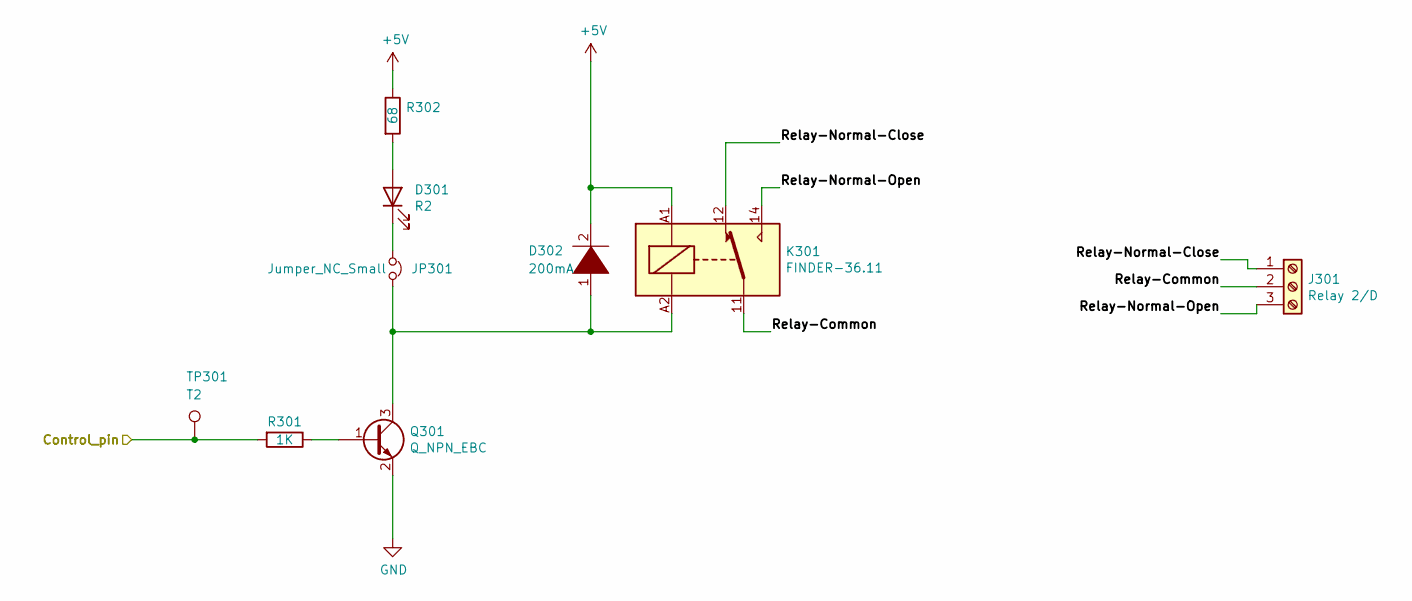
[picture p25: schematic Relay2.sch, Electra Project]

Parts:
D301: R2; LED_0603_1608Metric_Pad1.05x0.95mm_HandSolder; LCSC C2286
D302: 200mA; D_MiniMELF; LCSC C9808
J301: Relay 2/D; TerminalBlock_bornier-3_P5.08mm; LCSC C8425
JP301: Jumper_NC_Small; SolderJumper-2_P1.3mm_Bridged_RoundedPad1.0x1.5mm
K301: FINDER-36.11; Relay_SPDT_Finder_36.11; LCSC C399562
Q301: Q_NPN_EBC; SOT-323_SC-70; LCSC C75568
R301: 1K; R_0603_1608Metric_Pad0.98x0.95mm_HandSolder; LCSC C21190
R302: 68; R_0603_1608Metric_Pad0.98x0.95mm_HandSolder; LCSC C27592
TP301: T2; TestPoint_Pad_D1.5mm

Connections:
+5V: D302.2 (A), K301.A1, R302.1; also elsewhere on the board
/Relay2: R301.2, TP301.1; also elsewhere on the board
/Relay2/Relay-Common: J301.2, K301.11
/Relay2/Relay-Normal-Close: J301.1, K301.12
/Relay2/Relay-Normal-Open: J301.3, K301.14
GND: Q301.2 (E); also elsewhere on the board
unnamed: D301.1 (K), JP301.1
unnamed: D301.2 (A), R302.2
unnamed: D302.1 (K), JP301.2, K301.A2, Q301.3 (C)
unnamed: Q301.1 (B), R301.1

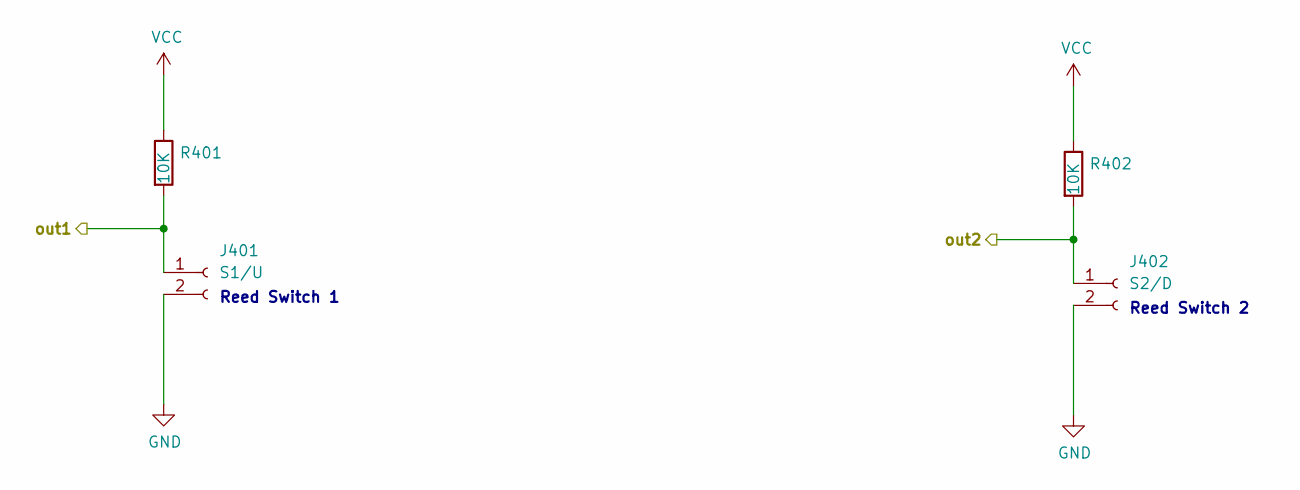
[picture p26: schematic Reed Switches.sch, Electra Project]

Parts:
J401: S1/U; JST_XH_B2B-XH-A_1x02_P2.50mm_Vertical
J402: S2/D; JST_XH_B2B-XH-A_1x02_P2.50mm_Vertical
R401, R402: 10K; R_0603_1608Metric_Pad0.98x0.95mm_HandSolder; LCSC C25804

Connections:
+3V3: R401.1, R402.1; also elsewhere on the board
/Switch1: J401.1, R401.2; also elsewhere on the board
/Switch2: J402.1, R402.2; also elsewhere on the board
GND: J401.2, J402.2; also elsewhere on the board

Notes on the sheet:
Reed Switch 1
Reed Switch 2

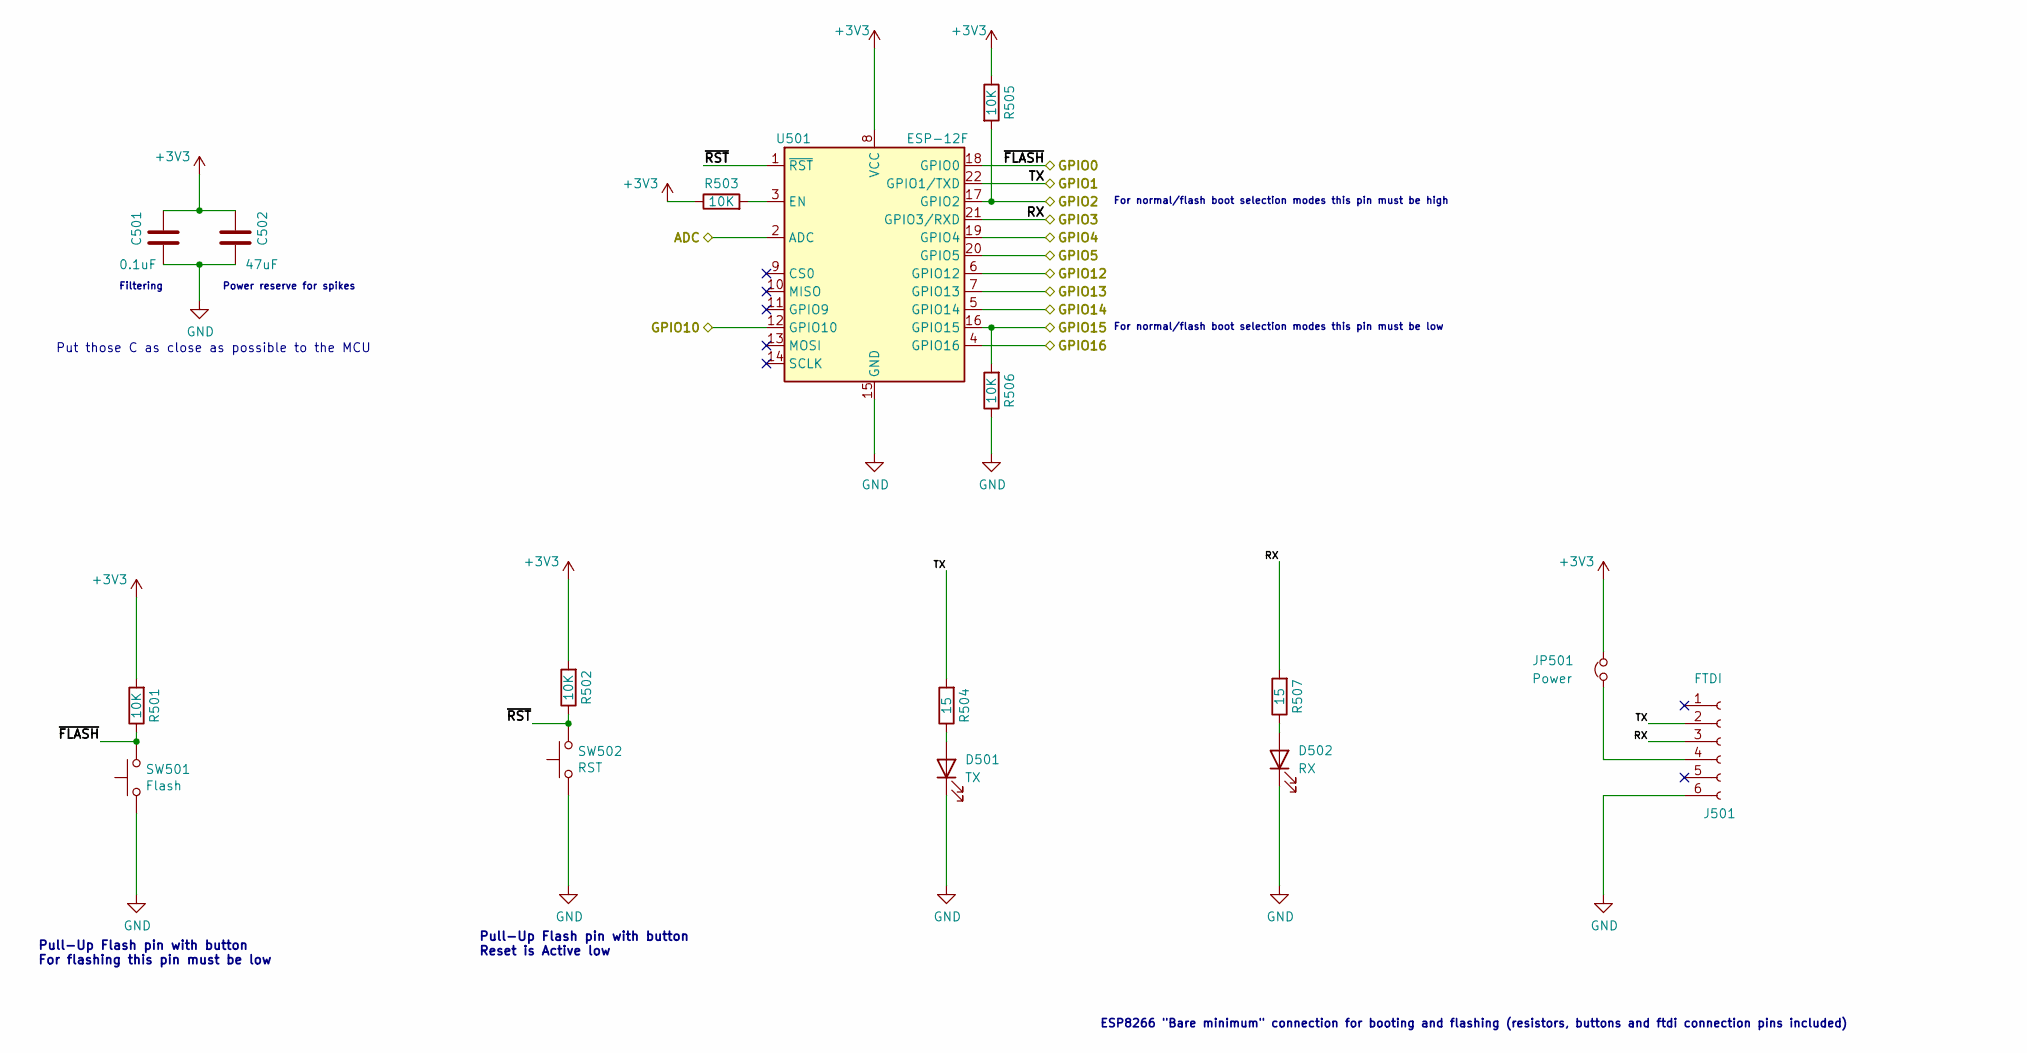
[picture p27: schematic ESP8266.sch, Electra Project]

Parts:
C501: 0.1uF; C_0603_1608Metric_Pad1.08x0.95mm_HandSolder; LCSC C14663
C502: 47uF; C_1206_3216Metric_Pad1.33x1.80mm_HandSolder; LCSC C96123
D501: TX; LED_0603_1608Metric_Pad1.05x0.95mm_HandSolder; LCSC C72041
D502: RX; LED_0603_1608Metric_Pad1.05x0.95mm_HandSolder; LCSC C72041
J501: FTDI; PinHeader_1x06_P2.54mm_Vertical
JP501: Power; SolderJumper-2_P1.3mm_Bridged_RoundedPad1.0x1.5mm
R501, R502, R503, R505, R506: 10K; R_0603_1608Metric_Pad0.98x0.95mm_HandSolder; LCSC C25804
R504, R507: 15; R_0805_2012Metric_Pad1.20x1.40mm_HandSolder; LCSC C17480
SW501: Flash; SW_SPST_CK_RS282G05A3; LCSC C319365
SW502: RST; SW_SPST_CK_RS282G05A3; LCSC C319365
U501: ESP-12F; ESP-12E; LCSC C82891

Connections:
+3V3: C501.1, C502.1, JP501.2, R501.2, R502.2, R503.1, R505.1, U501.8 (VCC); also elsewhere on the board
/ESP8266/ADC: U501.2 (ADC); also elsewhere on the board
/ESP8266/GPIO0: R501.1, SW501.2, U501.18 (GPIO0)
/ESP8266/GPIO14: U501.5 (GPIO14); also elsewhere on the board
/ESP8266/~RST: R502.1, SW502.2, U501.1 (~RST)
/Extra1: U501.12 (GPIO10); also elsewhere on the board
/Extra2: R505.2, U501.17 (GPIO2); also elsewhere on the board
/L-SDA: U501.19 (GPIO4); also elsewhere on the board
/L-SDL: U501.20 (GPIO5); also elsewhere on the board
/RX: J501.3, R507.2, U501.21 (GPIO3/RXD); also elsewhere on the board
/Relay1: U501.7 (GPIO13); also elsewhere on the board
/Relay2: R506.2, U501.16 (GPIO15); also elsewhere on the board
/Switch1: U501.6 (GPIO12); also elsewhere on the board
/Switch2: U501.4 (GPIO16); also elsewhere on the board
/TX: J501.2, R504.2, U501.22 (GPIO1/TXD); also elsewhere on the board
GND: C501.2, C502.2, D501.1 (K), D502.1 (K), J501.6, R506.1, SW501.1, SW502.1, U501.15 (GND); also elsewhere on the board
unnamed: D501.2 (A), R504.1
unnamed: D502.2 (A), R507.1
unnamed: J501.4, JP501.1
unnamed: R503.2, U501.3 (EN)

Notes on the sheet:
ESP8266 "Bare minimum" connection for booting and flashing (resistors, buttons and ftdi connection pins included)
For normal/flash boot selection modes this pin must be high
For normal/flash boot selection modes this pin must be low
Pull-Up Flash pin with button Reset is Active low
Filtering
Power reserve for spikes
Pull-Up Flash pin with button For flashing this pin must be low
Put those C as close as possible to the MCU

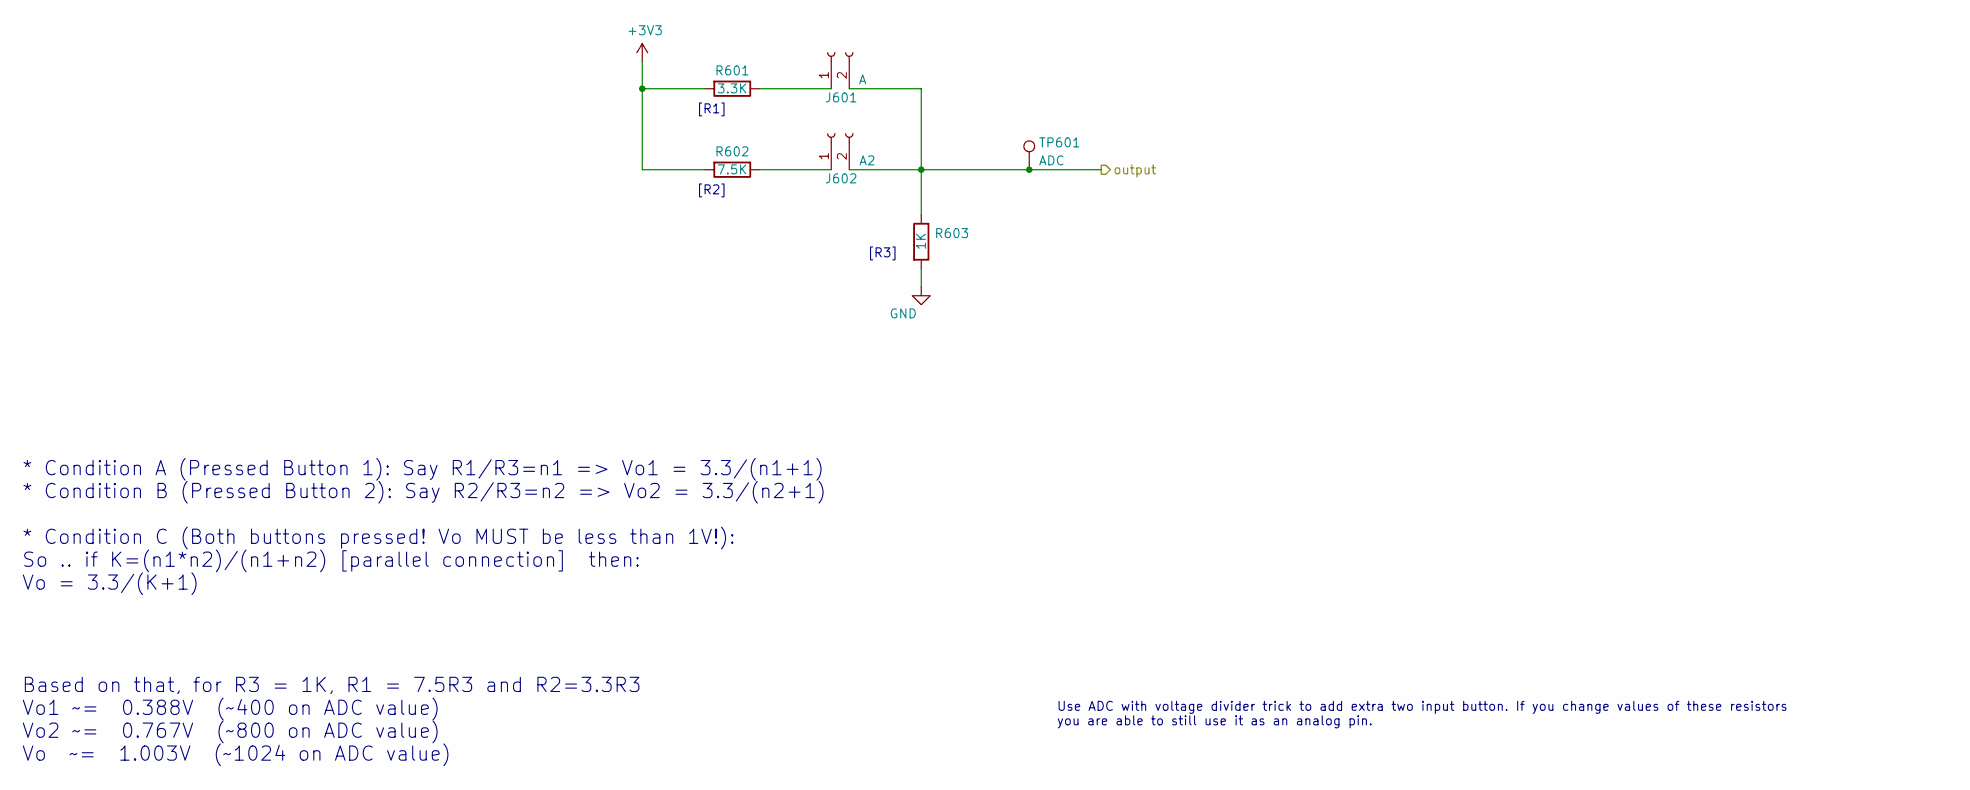
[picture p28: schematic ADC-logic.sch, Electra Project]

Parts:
J601: A; JST_XH_B2B-XH-A_1x02_P2.50mm_Vertical
J602: A2; JST_XH_B2B-XH-A_1x02_P2.50mm_Vertical
R601: 3.3K; R_0603_1608Metric_Pad0.98x0.95mm_HandSolder; LCSC C22978
R602: 7.5K; R_0603_1608Metric_Pad0.98x0.95mm_HandSolder; LCSC C23234
R603: 1K; R_0603_1608Metric_Pad0.98x0.95mm_HandSolder; LCSC C21190
TP601: ADC; TestPoint_Pad_D1.5mm

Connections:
+3V3: R601.2, R602.2; also elsewhere on the board
/ESP8266/ADC: J601.2, J602.2, R603.1, TP601.1; also elsewhere on the board
GND: R603.2; also elsewhere on the board
unnamed: J601.1, R601.1
unnamed: J602.1, R602.1

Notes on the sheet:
[R3]
[R1]
[R2]
* Condition A (Pressed Button 1): Say R1/R3=n1 => Vo1 = 3.3/(n1+1) * Condition B (Pressed Button 2): Say R2/R3=n2 => Vo2 = 3.3/(n2+1) * Condition C (Both buttons pressed! Vo MUST be less than 1V!): So .. if K=(n1*n2)/(n1+n2) [parallel connection] then: Vo = 3.3/(K+1)
Use ADC with voltage divider trick to add extra two input button. If you change values of these resistors you are able to still use it as an analog pin.
Based on that, for R3 = 1K, R1 = 7.5R3 and R2=3.3R3 Vo1 ~~= 0.388V (~~400 on ADC value) Vo2 ~~= 0.767V (~~800 on ADC value) Vo ~~= 1.003V (~~1024 on ADC value)

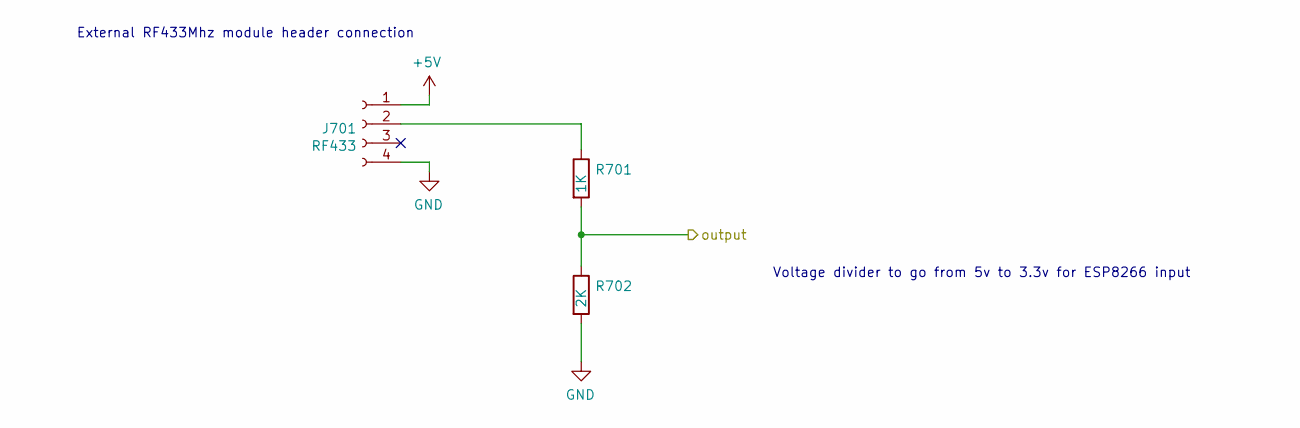
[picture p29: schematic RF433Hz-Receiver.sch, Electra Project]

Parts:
J701: RF433; PinHeader_1x04_P2.54mm_Vertical
R701: 1K; R_0603_1608Metric_Pad0.98x0.95mm_HandSolder; LCSC C21190
R702: 2K; R_0603_1608Metric_Pad0.98x0.95mm_HandSolder; LCSC C22975

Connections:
+5V: J701.1; also elsewhere on the board
/ESP8266/GPIO14: R701.2, R702.1; also elsewhere on the board
GND: J701.4, R702.2; also elsewhere on the board
unnamed: J701.2, R701.1

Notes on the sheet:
External RF433Mhz module header connection
Voltage divider to go from 5v to 3.3v for ESP8266 input

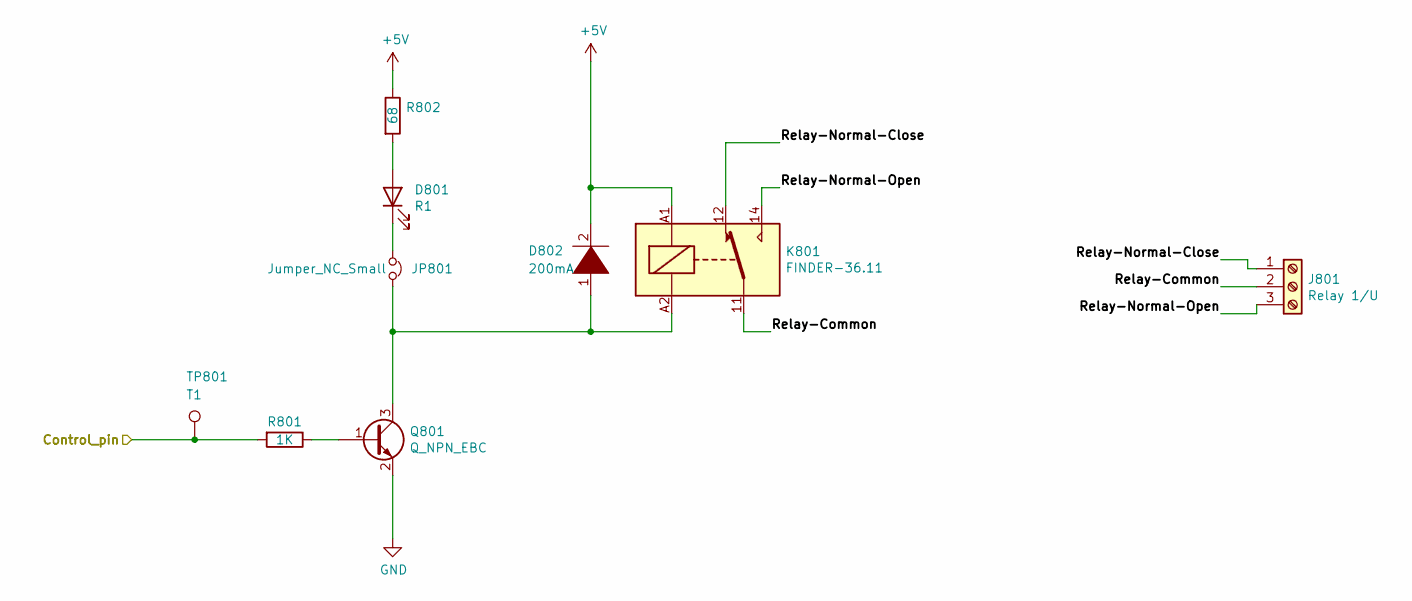
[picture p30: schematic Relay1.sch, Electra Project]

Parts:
D801: R1; LED_0603_1608Metric_Pad1.05x0.95mm_HandSolder; LCSC C2286
D802: 200mA; D_MiniMELF; LCSC C9808
J801: Relay 1/U; TerminalBlock_bornier-3_P5.08mm; LCSC C8425
JP801: Jumper_NC_Small; SolderJumper-2_P1.3mm_Bridged_RoundedPad1.0x1.5mm
K801: FINDER-36.11; Relay_SPDT_Finder_36.11; LCSC C399562
Q801: Q_NPN_EBC; SOT-323_SC-70; LCSC C75568
R801: 1K; R_0603_1608Metric_Pad0.98x0.95mm_HandSolder; LCSC C21190
R802: 68; R_0603_1608Metric_Pad0.98x0.95mm_HandSolder; LCSC C27592
TP801: T1; TestPoint_Pad_D1.5mm

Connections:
+5V: D802.2 (A), K801.A1, R802.1; also elsewhere on the board
/Relay1: R801.2, TP801.1; also elsewhere on the board
/Relay1/Relay-Common: J801.2, K801.11
/Relay1/Relay-Normal-Close: J801.1, K801.12
/Relay1/Relay-Normal-Open: J801.3, K801.14
GND: Q801.2 (E); also elsewhere on the board
unnamed: D801.1 (K), JP801.1
unnamed: D801.2 (A), R802.2
unnamed: D802.1 (K), JP801.2, K801.A2, Q801.3 (C)
unnamed: Q801.1 (B), R801.1

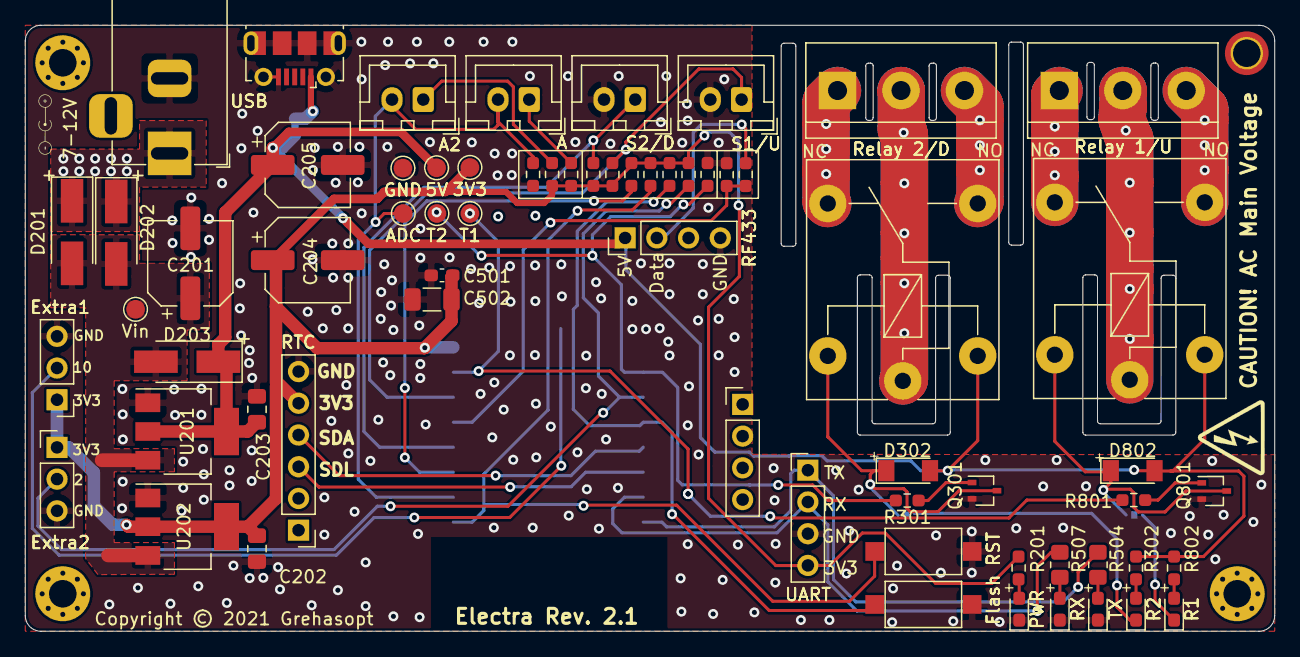
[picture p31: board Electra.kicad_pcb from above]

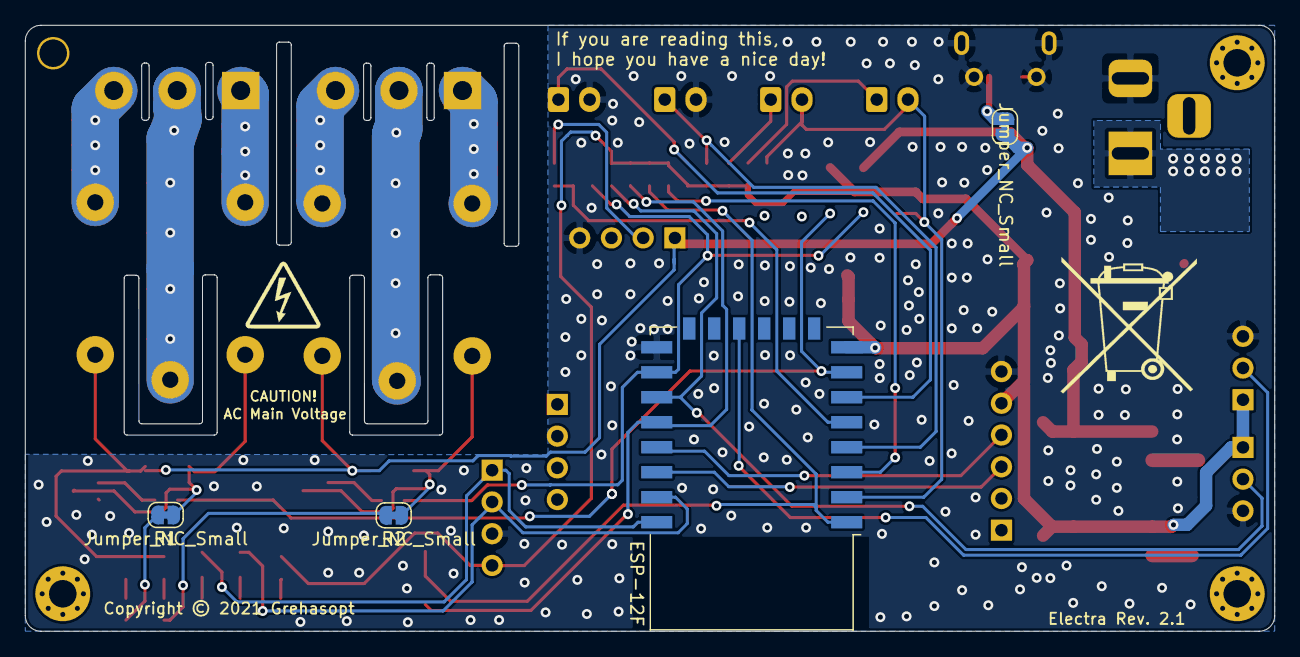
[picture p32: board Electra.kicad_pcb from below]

Board: 2 copper layers, 100.0 x 48.5 mm, 68 parts (4 on the bottom side), 41 nets.

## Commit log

2021-03-21 Basic schematic added v1
    [ADC-logic.sch, ESP8266.sch, Electra.sch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]
2021-03-24 PCB Ver 1 completed (TODO: Check)
    [ADC-logic.sch, ESP8266.sch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]
2021-03-25 PCB completed (added silkscreen more)
    [ADC-logic.sch, ESP8266.sch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]
2021-03-27 Pcb completed with 3D model
    [Electra.kicad_pcb]
2021-03-28 Panel added, gerbs added
    [Electra-B_Cu.gbr, Electra-B_Mask.gbr, Electra-B_SilkS.gbr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]
2021-03-28 Release 1.0 | Rev 1.0 (TPS54202DDCR out of stock) use different buck converter
    [LCSC_Exported_20210329_040204.csv]
2021-04-01 Rev 2 completed, todo check all and remove not needed filed
    [ADC-logic.sch, ESP8266.sch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]
2021-04-02 IMPORTANT! REV 2 completed! Send to fabrication
    [Electra-B_Cu.gbr, Electra-B_Mask.gbr, Electra-B_SilkS.gbr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]
2021-05-04 Clean some vias and clean up files
    [Electra-bu.kicad_pcb, Electra-with-tag.kicad_pcb, Electra.csv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]
2021-05-04 Minor fixes on schematic and pcb fix bjt netlist + ac main voltage to both sides (Rev 2.1)
    [ADC-logic.sch, ESP8266.sch, Electra.kicad_pcb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]

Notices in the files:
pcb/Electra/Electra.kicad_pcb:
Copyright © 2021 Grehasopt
